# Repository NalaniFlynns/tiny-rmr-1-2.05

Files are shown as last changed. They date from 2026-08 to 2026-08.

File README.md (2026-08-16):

# tiny-rmr-1-2.05 —— RMR 1:2.05 微型反射式红点瞄准镜（固件 + 设计 + 调试器）

> 完整说明书（固件特性/算法/按键操作/NVM 配置/编译烧录/调试）：**[docs/RMR_说明书.md](docs/RMR_说明书.md)**

---

## 更新记录：2026-08-15（晚），固件 V4.3.5：量产版默认禁 SWD/NRST（仅 FLASH_MODE 开放）+ STANDBY1 移除周期轮询唤醒
- **量产版默认禁 SWD + NRST（FEATURE_PROD_SWD_DISABLE，仅 DIRECT/BATT/ECO_D/ECO_B 量产构建生效）**：正常运行时写 SWDCFG/EXRSTPIN 一次性禁用（**仅 POR 可恢复**），SWD/调试口在量产固件中默认关闭；**FLASH_MODE 是唯一调试通道**——每次复位（POR/热复位）后 5 秒 boot 窗口内 BT1 短按 0.8s 进入 FLASH_MODE（任意运行态，含自动开机后的 RUN），窗口内 SWD/NRST 全程开放；窗口结束且不在 FLASH_MODE 即禁用，之后需**重新上电**才能再连。FLASH_MODE 会话内从不禁用，保证烧录通道；退出后由窗口判定补禁。DBG/DBGL 调试版不启用该特性，调试期 SWD 全程可连
- **重新烧录量产固件的操作**：断电 → 重新上电 → **5 秒内短按 BT1（0.8s）** 进 FLASH_MODE（LED 闪两下）→ RMRDebugger 连接烧录；烧录完成复位后如需再次烧录，重复断电上电即可
- **STANDBY1 移除 750ms 周期轮询（省电）**：实测 WUEN/WCOMP + GPIO 边沿唤醒可靠无失败（历史"概率失败"根因是 standby 入口被 WWDT 违规复位/残留标志破坏，V4.3.4 已修复），移除 TIMG14 32k 周期轮询——深睡前停 TIMG14 表，唤醒后重启 1ms tick；消除每 ~750ms 一次的 ~20uA 电流尖峰，standby 电流恒定 <1uA
- **自动关机时长修正**：40min 无操作调暗 + **50min 延迟关机**（TIME_AUTO_SHUTDOWN_S 600→3000，总 90min）
- **省电版（ECO）FLASH_MODE 最小遥测**：POWER_SAVE_BUILD 常态不刷 mailbox 省电，进 FLASH_MODE 后刷最小遥测（VBATT/状态/PWM/standby 计数等）供 RMRDebugger 显示
- **验证**：六变体全部重建（V4.3.5_DBG/DBGL/DIRECT/BATT/ECO_D/ECO_B，0 错误 0 警告）；hex 体检确认 SWDCFG(0x62000001)/EXRSTPIN(0x1E000001) 写序列仅在量产 hex 出现；发布镜像 firmware/RMR.hex = V4.3.5_DIRECT；RMRDebugger 内置 fw/ 同步更新（BATT/DBGL/DIRECT/ECO_D/ECO_B）
- **注意**：量产固件烧录后 SWD 默认关闭属预期；RMRDebugger 在烧录完成复位后若连接在 5s 窗口外断开，属正常行为，重新上电+FLASH_MODE 即可恢复

## 更新记录：2026-08-15（下午），固件 V4.3.4 补丁：修复计时快 6 倍（1.5s 一按就亮/5s 不满）+ 关机不进 STANDBY1
- **修复 1（计时快 ~6 倍，根因）**：MSPM0C110x 的 SYSOSC **实际只能运行在 24MHz**——写 SYSOSCCFG.FREQ=1（4M）寄存器生效但硅片仍以 24MHz 跑，而代码又按 4M 把 TIMG14 LOAD 设成 4000，导致 g_tick_ms 变成 167us/tick。所有基于 tick 的计时（双键 1.5s 开机/关机、5s 模式切换、LVP/ALS 时延）被压缩约 6 倍：表现为"一按就亮、5s 也不满"。修复：`sysclk_set_freq()` 恒定 24MHz、LOAD 恒为 24000-1，g_tick_ms 恒为真 1ms（实测 2036 tick/2s 墙钟）；OFF 态短暂运行不降频（STANDBY1 深睡停机才是 uA 级功耗来源）
- **修复 2（关机后不进 STANDBY1）**：关机路径 `g_off_pending` 在 5s 事件/异常松开后残留为 1，把深睡分支 `!g_off_pending` 卡死 → PMODECFG 恒 0、SWD 不断开。修复：OFF 态深睡前自愈——`g_off_pending && key_is_idle()` 则清零；同时 hal_keys 在干净松开（双键均释放且上一拍非双键）时复位 both_released/both_handled_1_5s/both_handled_5s/both_release_handled/both_down_tick，防止残留导致下一次双按瞬间判定超时长按
- **修复 3（mailbox 时钟上报）**：`sys_clk_khz` 恒报 24000（不再按 SYSOSCCFG.FREQ 报 4000，那只是寄存器假象）
- **修复 4（自动降亮度/关机计时不准，V4.3.4 补丁 2）**：`g_tick_ms % 1000 == 0` 在 delay_cycles 忙等构建（DIRECT/BATT/DBG）主循环 >1ms 时会漏整秒边界（实测计数率仅 0.37/s，40min 会拖到 ~108min）；改为 tick 差值计数（`g_tick_ms - last_sec_tick >= 1000`），实测 1/s 精确，40s 测试参数下 dim 在 ~41s、关机在 ~60s 触发
- **新增 STANDBY 确认计数（mailbox 0xC0）**：`standby_entry_cnt` 每次 OFF 会话第一次真正进入 STANDBY1 前 +1（SRAM 在 STANDBY1 下保留，唤醒后可读）；RMRDebugger 新增 "stby_cnt" 显示 + 修复 sys_clk 显示（新固件报 24000，旧逻辑只认 32000/4000 会显示 "-"）。实测 cmd=7 关机后 stby_cnt 0→1、PMODECFG=1、SWD 断开
- **验证**：六变体全部重建（V4.3.4_DBG/DBGL/DIRECT/BATT/ECO_D/ECO_B，0 错误 0 警告）；RMRDebugger 烧录 RMR_DBGL.hex 后实测：g_tick_ms 真 1ms；mailbox cmd=7 关机后 PMODECFG=1（SYSCTL_PMODECFG_DSLEEP_STANDBY）、内核寄存器不可读、SWD 断开 → **STANDBY1 已真实进入**。实体按键 1.5s 开机/关机、5s 切换待物理验证
## 更新记录：2026-08-15，固件 V4.3.4：修复上电自动开机失效 + STANDBY1 按键无法开机（唤醒加固）
- **修复 1（上电自动开机失效，根因）**：V4.3.3 的 NVM off-intent 哨兵（
eserved[0]=0x5A）用 (cold_boot || !g_off_intent) && !nvm_off_intent_get() 把**冷启动也拦截**——正常断电再上电时 SRAM 丢失但 NVM 哨兵仍在 → 永不自动开机。修复为 cold_boot || (!g_off_intent && !nvm_off_intent_get())：真实上电永远放行 AUTO_POWER_ON（启动成功即清哨兵），仅热复位（WWDT/调试器）带 off-intent 时保持关机
- **修复 2（STANDBY1 按键无法开机，唤醒加固）**：原深睡只依赖 WUEN/WCOMP + GPIO 边沿唤醒，历史概率性失效导致按键无响应。数据手册确认 STANDBY1 下 TIMG14 由 32k LFCLK 驱动且 PD0 中断可唤醒——改为**不停 TIMG14、不屏蔽其中断**，LOAD=24000 → ~750ms 周期中断唤醒轮询按键（STANDBY_TIMG14_LOAD_32K），WUEN 保留即时唤醒；周期唤醒无按键时**跳过 battery_resume 省电**，按键唤醒才重测电压；唤醒后显式 sysclk_set_freq(false) 恢复关机态 4MHz/1ms tick
- **调试信箱尾部扩展（V4.3.4+，0xB8 起）**：追加 sys_clk_khz（SYSOSCCFG.FREQ → 32000/4000）与 oot_refuse_reason（0=OK / 1=测压门拒绝 / 2=off-intent 保持关机 / 3=自动开机未使能）；RMRDebugger 新增 "Sys Clk / Boot Refuse" 遥测显示（旧固件自动显示 "-"）
- **产物**：六变体 hex 全部重建（DIRECT/BATT/ECO_D/ECO_B/DBG/DBGL，V4.3.4），发布镜像 firmware/RMR.hex（V4.3.4_DIRECT）；RMRDebugger 重新编译（rmrdebuger.exe）并更新内置 
w/ 烧录固件
- **掉电保存优化（empty_mspm0c1104.c）**：快速掉电（单次原始电压 < 2000mV 即触发，不再等 3 次采样）→ **瞬间断开 PWM**（直接写 0% 占空比 + 停计数器，LED 停止耗电让电压回升稳定）→ **立即强制保存** NVM → SHUTDOWN（调试版仅保存保 SWD）；缓慢掉电/关机路径（LVP_EXT/LVP_CRIT 连续 5 次采样确认）保持不变——关机才多次采样
- **cfg_params 镜像冻结修复（test_mailbox.c）**：`test_box_sync_cfg()` 同步后未更新 `last_synced_params` 守卫值，导致写配置/模式切换后调试器显示 `cfg_params` 永久冻结为旧值；实机验证（sys_memory.params 0x00020104 vs 镜像 0x00020004）确认并修复
- **说明书重构（docs/RMR_说明书.md）**：前半部分改为**用户手册**——对象用户与阅读指引、快速上手、完整操作手册（开机关机/亮度/模式切换/FLASH）、指示灯速查、机制介绍（低电量/严重低电量/断电保护/测压门控/自动关机/ALS 故障）、12 条常见问题 QA；技术细节（算法/NVM/调试接口/编译烧录）后置
- **产物**：六变体 hex 全部干净重建并逐个体检版本串（DIRECT/BATT/ECO_D/ECO_B/DBG/DBGL），0 错误 0 警告
## 更新记录：2026-08-14，修复“只能切 ALS 无法切回 MAN”
- **根因**：RUN 态双键按住 1.5s 即熄灯进入 OFF，继续按到 5s 时状态已在 OFF，而 OFF 分支的 5s 处理**无条件强制 ALS 开机**——导致从 ALS 永远切不回 MAN（熄灯→5s→又 ALS）
- **修复 1（模式互切）**：`empty_mspm0c1104.c` OFF 态 5s 事件区分来源——来自 RUN 熄灯路径（`g_off_pending`）时**切换 ALS<->MAN 并重新亮灯**；OFF 直接长按/开机失败重试仍为 ALS 快捷开机；NVM 写入改为按位设置支持清零
- **修复 2（ALS 锁定可退出）**：`sys_mode.c` 传感器故障锁定（lockout）后，**ALS 模式仍可切回手动**（原逻辑无条件拒绝所有切换导致卡死）；手动切 ALS 仍被拒以防闪烁循环
- **产物**：六变体 hex 全部重建（DIRECT/BATT/ECO_D/ECO_B/DBG/DBGL）+ 发布镜像 firmware/RMR.hex，0 错误 0 警告

## 更新记录：2026-08-14，无操作超时调整 + 新增完整说明书
- **超时调整**：无操作调暗由 60 分钟改为 **40 分钟**（`TIME_AUTO_DIM_S` 3600→2400），调暗后再 **10 分钟**无操作自动关机（`TIME_AUTO_SHUTDOWN_S=600` 不变）
- **说明书**：新增 [docs/RMR_说明书.md](docs/RMR_说明书.md)（固件特性确认/电压补偿算法/按键操作/状态机/NVM 配置/调试接口/编译烧录）
- **六变体 hex 全部重建**：DIRECT / BATT / ECO_D / ECO_B / DBG / DBGL（含发布镜像 firmware/RMR.hex），源码与 CCS 工作区同步

## 更新记录：2026-08-13，双键关机确认机制（灭灯≠standby）+ RMRDebugger 烧录修复
- **状态**：RUN 态双键满 1.5s 立即熄灯，继续按住到 5s 转 ALS 亮灯
- **机制**：1.5s 熄灯后进入 SYS_OFF，但不再立刻进 STANDBY0（防止 WCOMP/GPIO 唤醒源误触发导致“松开灯又亮”）
- **关机确认**：新增“灭灯≠standby”逻辑，`hal_keys.c` 新增 `EVT_BOTH_RELEASE_1_5S`：1.5s 熄灯后若未满 5s 松开 → 保持关机并进 standby；`empty_mspm0c1104.c` 新增 `g_off_pending` 门控，1.5s 后仅置 pending，确认松开才进 STANDBY0；按住满 5s → 清 pending + 闪烁 + ALS 亮灯
- **RMRDebugger 烧录修复**：`debugworkers.cpp` executeFlash 在 program 前加 `halt` + `flash probe 0`，若 target 无法 halt / FACTORYREGION flash size=0 → 提示 "Target missing or protected"；烧录后清 SRAM 开机门控 `g_off_intent`=0x20000299 / `g_por_magic`=0x2000029C，模拟冷启动自动亮灯（避免“烧录后 OFF 不亮灯”）
- **产物**：DEBUG_LP_BUILD / DEBUG_BUILD / 默认三配置 0 错误 0 警告；`firmware/RMR/hex/RMR_DBGL.hex`（V4.3.3_DBGL）已更新，RMRDebugger 烧录验证：1.5s 熄灯松开后保持 standby，5s 转 ALS + 亮灯
## 更新记录：2026-08-11，深睡后“松开灯又亮”根因修复（双键 1.5s 熄灯 → 松开应保持灭灯）
- 症状：RUN 态双键按住满 1.5s 灯灭后，松开灯又亮（独立供电同样复现）。根因并非按键/邮箱逻辑，而是深睡路径三处硬件级缺陷叠加
- 根因 1（WWDT 拉伸未生效）：进入 STANDBY0 前代码先 `DL_WWDT_restart()` 再写 `WWDTCTL0` 拉伸周期——但 MSPM0 的 WWDT **新周期只在下次计数器重启时装载**，顺序反了导致深睡期间仍是 500ms 周期，约 0.5s 后 WWDT 超时复位设备。修复：**先写 `WWDTCTL0` 拉伸配置，再 `DL_WWDT_restart()`**，深睡时实际生效 ~8192s 周期
- 根因 2（IOMUX 唤醒比较方向错误）：按键为低有效（空闲=1、按下=0），代码却配 `DL_GPIO_WAKEUP_COMPARE_VALUE_1`（匹配高电平）——进 standby 时引脚已为高 → 立即误唤醒/无法保持深睡；按下（1→0）不产生唤醒 → “有概率按键无法开机唤醒”。修复：改为 **`DL_GPIO_WAKEUP_COMPARE_VALUE_0`**（匹配低电平，按下即异步唤醒）
- 根因 3（AUTO_POWER_ON 不区分复位来源）：`FEATURE_AUTO_POWER_ON` 在**任何复位**后都自动开机。WWDT 复位 → 重启 → 看到 NVM 中 auto-power-on 标志 → 直接 RUN → 灯亮。修复：启动时读 `SYSCTL->SOCLOCK.RSTCAUSE`（读后自动清零，仅冷启动 POR/BOR/SHUTDOWN 退出视为 first_boot），**WWDT/SYSRST/调试复位一律保持关机**；`RSTCAUSE` 为 0 时用 `.TI.noinit` SRAM magic 兜底
- 新增观测：`g_test_box.rst_cause`（复用原 `_pad0` 字节，偏移不变，调试器无需改布局）镜像本次复位原因；`g_debug_str` 追加 `Rst:xx` 字段，烧录后可确认复位来源（0x0E=WWDT0 违规）
- 验证：DEBUG_LP_BUILD / DEBUG_BUILD / 默认三配置 0 错误 0 警告；`firmware/RMR/hex/RMR_DBGL.hex`（V4.3.3_DBGL）已更新并已通过 RMRDebugger 烧录（OpenOCD Verify OK）。待独立供电实测：双键 1.5s 熄灯 → 松开保持灭灯；关机态按任意键应立即唤醒（不再等松开）
## 更新记录：2026-08-11，按键交互调整：双键长按 1.5s 立即熄灯 / 5s 转 ALS 亮灯 / 中途松开关机
- **RUN/LVP 态按住双键**：1.5s 到点**立即熄灯**（无需松开），进入 OFF；继续按住到 5s → 闪烁提示（led_blink_twice）并**以 ALS 模式开机**（测压达标才启动，强制写入 ALS 标志并落盘）；1.5s~5s 之间松开 → 保持关机
- **实现**：`hal_keys.c` 1.5s 事件由"仅 OFF 态按住触发"改为全状态按住触发（RUN 态立即响应熄灯）；`empty_mspm0c1104.c` OFF 态新增 `EVT_BOTH_LONG_5S` 分支（闪烁 + ALS 开机）
- **保持原行为**：OFF 态双键 1.5s 开机、RUN 态 5s 模式切换（ALS<->手动，TEST 态同）、FLASH 模式单键 0.8s 进入、调试器恢复出厂指令均不变
- **验证**：DEBUG_LP_BUILD / DEBUG_BUILD / 默认三配置 0 错误 0 警告；`firmware/RMR/hex/RMR_DBGL.hex`（V4.3.3_DBGL）已更新
## 更新记录：2026-08-11，固件深睡唤醒修复（STANDBY0 按键唤醒/进入 standby 概率性问题）
- **根因 1：WWDT 深睡复位**：WWDT 由 LFCLK 驱动，`DL_WWDT_STOP_IN_SLEEP` 只覆盖 SLEEP 模式；进入 STANDBY0 后 LFCLK 继续运行，500ms 看门狗因主循环停摆而超时 → 每 500ms 周期性 SYSRST，导致"有概率无法进入 standby"且按键唤醒被复位窗口吞掉。修复：进入 STANDBY0 前将 WWDT 周期临时拉伸到最大（PER_EN_25 + CLKDIV /8 ≈ 8192s），唤醒后立即恢复 500ms 配置并喂狗
- **根因 2：唤醒源只配了 GPIO 边沿中断**：STANDBY0 深睡下边沿中断依赖 ULPCLK 采样，按下瞬间易被丢失。修复：新增 IOMUX IO 唤醒（`DL_GPIO_setWakeupCompareValue` + `DL_GPIO_enableWakeUp`，WCOMP 匹配高电平、按键按下拉低即异步唤醒），GPIO 边沿中断保留作双保险；唤醒后 `DL_GPIO_disableWakeUp` 清理
- **根因 3：WFI 可被 1ms tick 打断**：进入深睡前清 `GPIOA/TIMG14` pending，并用 `__disable_irq()/__WFI()/__enable_irq()` 受控进入，杜绝"概率性无法进入 standby"的 tick 竞态
- **修复代码位置**：`empty_mspm0c1104.c` OFF 深睡段（STANDBY0 入口/出口），对 `DEBUG_LP_BUILD`、正式版（FLAG_SWD_IN_OFF_STATE 未置位）同样生效
- **验证**：`DEBUG_LP_BUILD=1` / `DEBUG_BUILD=1` / 默认三配置均 0 错误 0 警告；产物 `firmware/RMR/hex/RMR_DBGL.hex`（V4.3.3_DBGL）已更新，建议重新烧录后实测：power off → 深睡（电流应稳定 μA 级无周期性尖峰）→ 双键 1.5s 应 100% 唤醒开机
## 更新记录（2026-08-11，RMRDebugger：Power-Z 平均统计）
- **Power-Z 10s 滑动窗口平均统计**：`PowerZWorker` 新增软件统计——200ms 采样压入窗口、弹出超窗样本，实时计算最近 10s 平均电压/电流/功耗（约 50 样本）
- **GUI**：Power-Z 区域新增一行 `Avg V / Avg I / Avg P / 10s Win(s)` + `Reset Stats` 按钮（清零重填窗口）
- **IPC**：`hello` 与 `powerz` 事件新增 `avg_v / avg_a / avg_w / stat_sec` 字段；新增命令 `{"cmd":"powerz","reset":true}` 清零统计
- **验证**：KM003C 已连接实测——`avg_v` 3.2009V 稳定、窗口满后 `stat_sec` 保持 ~10s、清零后从 0 重新填充；`rmrdebuger.exe` 已更新（firmware/RMRDebugger/ 与 RMR_Factory_Tool_V2.0/）
## 更新记录（2026-08-11，固件 V4.3.3 低功耗调试版 DEBUG_LP_BUILD：OFF 态 WFI/STANDBY0 深睡 + 开机态 SWD，已烧录验证）
- **新增调试编译宏 `DEBUG_LP_BUILD`**（`app_config.h`，默认 0，与 `DEBUG_BUILD`/`POWER_SOURCE_DIRECT`/`POWER_SAVE_BUILD` 正交）：1=低功耗调试专用，版本串 `V4.3.3_DBGL`
- **OFF 态彻底低功耗**：强制进入深睡段（关 ADC/VREF + WFI + STANDBY0，忽略 NVM SWD 位），SWD 自然断开可接受；出厂默认清 `FLAG_SWD_IN_OFF_STATE`
- **开机/运行态 SWD 保持**：RUN 态正常可调试，telemetry 实时；掉电保护不执行 SHUTDOWN（仅存脏配置），主循环 WFI 睡眠等待 1ms tick
- **保留特性**：ECO 动态降频、NVM 校验/重试/多槽位、ALS 故障锁、LVP、FLASH 模式等全部不变
- **产物**：`firmware/RMR/hex/RMR_DBGL.hex`（`V4.3.3_DBGL`）
- **验证**：DEBUG_LP_BUILD=1 与 =0 均 0 错误 0 警告；已烧录测试板：RUN 态 SWD+telemetry 实时；`power off` 后 STANDBY0 深睡（OpenOCD target unknown、数据冻结）；OpenOCD 复位唤醒后自动开机、SWD 自动重连
## 更新记录（2026-08-11，固件 V4.3.3 调试版 DEBUG_BUILD：测试板直供 + 全程 SWD，已烧录验证）
- **新增调试编译宏 `DEBUG_BUILD`**（`app_config.h`，默认 0，与 `POWER_SOURCE_DIRECT`/`POWER_SAVE_BUILD` 正交）：1=测试板直供调试专用，版本串 `V4.3.3_DBG`
- **全程 SWD 保活**（仅调试版生效，其余特性不变）：OFF 态跳过 STANDBY0 深睡段（不关 ADC/VREF、不 WFI 深睡）；掉电保护路径不执行 SHUTDOWN（仅保留脏配置落盘）；出厂默认置位 `FLAG_SWD_IN_OFF_STATE`
- **保留特性**：ECO 动态降频、NVM 校验/重试/多槽位、ALS 故障锁、LVP、FLASH 模式等全部不变
- **产物**：`firmware/RMR/hex/RMR_DBG.hex`（`V4.3.3_DBG`）
- **验证**：DEBUG_BUILD=1 与 =0 两配置均 0 错误 0 警告；已烧录测试板（XDS110 SWD），OFF 态 SWD 连接保持、telemetry 150ms 实时刷新
## 更新记录（2026-08-11，固件 V4.3.3 优化：ECO 动态降频 + NVM 磨损 + ALS 故障锁 + 杂项）
- **ECO 动态降频**：关机/FLASH 态 SYSOSC 切 4MHz 低功耗模式（24MHz→4MHz，睡眠电流大幅下降），开机/运行态自动恢复 24MHz；GPTIMER14 同步重配 LOAD，`g_tick_ms` 恒为真实 1ms（按键 1.5s/5s、FLASH 5min 超时、轮询计时全部不受影响）
- **NVM 磨损优化**：按键调档/模式切换不再立即写 FLASH，只置 dirty 交给 30s 后台自动保存（连按调档只记一次）；关机/LVP/掉电强制保存路径保留
- **ALS 故障锁**：连续 `ALS_ERR_LOCKOUT_COUNT`(3) 次 10s 自恢复后锁定 ALS——拒绝再切回（双键 5s 闪灯提示），防止传感器持续损坏时每 10s 闪一次死循环；重启/恢复出厂解除
- **启动延迟**：ECO 启动后先断 ADC/VREF 寄存器电源域，首次采样/开机测压前再上电；VREF 内部基准采样间隙关闭（`DL_VREF_enable/disableInternalRef` 门控，battery_startup_check/resume 同步）
- **flash 超时差值**：FLASH 模式 5min 超时改 `g_tick_ms` 差值比较（原累加计数，防 49.7 天回绕）
- **验证**：DIRECT / BATT / ECO_D / ECO_B 四变体 0 错误 0 警告；未烧录

## 更新记录（2026-08-11，固件 V4.3.3 省电版 ECO：关闭一切非必要开销，未烧录仅编译验证）
- **新增省电编译宏 `POWER_SAVE_BUILD`**（`app_config.h`，默认 0，与 `POWER_SOURCE_DIRECT` 正交）：1=省电版，版本串 `V4.3.3_ECO_D`（直连）/ `V4.3.3_ECO_B`（电池）
- **省电措施**：主循环 24MHz 忙等改 `__WFI()` 睡眠等待 1ms tick 中断（GPTIMER14 唤醒）；调试箱 `test_mailbox_task` 每 tick 实时刷新整体关闭（GPIO 读/64 位乘除/镜像同步/诊断计算）；ADC/VREF 采样间隙断电、采样间隔 500ms（原 100ms，LVP 去抖 5 次约 2.5s 响应）；OPT3001 手动模式与 OFF 态发 shutdown 配置（0.4µA 级，原连续转换约 1.8µA）；ALS 轮询 1s（原 120ms，转换占空比约 10%）；LED 亮度/状态未变化时不重算 PWM（原每 tick 64 位乘除+写寄存器）；出厂默认清 SWD 保活位 -> OFF 态进 STANDBY0 深睡（µA 级）
- **注意**：烧录省电版后若 NVM 已有旧配置（features=0xFF），OFF 态仍不会进 STANDBY0；需"恢复出厂"或经调试器清 bit6 才生效；省电版 OFF 态 SWD 不可访问（深睡保电），日常调试请用普通版
- **产物**：`firmware/RMR/hex/RMR_DIRECT_ECO.hex`（`V4.3.3_ECO_D`）、`RMR_BATT_ECO.hex`（`V4.3.3_ECO_B`）；普通版 DIRECT/BATT hex 同步刷新
- **验证**：DIRECT / BATT / ECO_D / ECO_B 四变体全部 0 错误 0 警告；未烧录（设备仍运行 V4.3.3_DIRECT）

## 更新记录（2026-08-11，固件 V4.3.3：FLASH 模式长按 1.5s 开机 + 调试器 cfg_features 实时显示）
- **固件 V4.3.3**：进入 FLASH 模式后双键长按 1.5s 也可正常开机——与 OFF 态一致先 `battery_startup_check()` 测压达标才启动（达标→SYS_RUN+mode_init，不达标→LED 闪 100ms 提示）；FLASH 模式 5 分钟超时自动复位逻辑保留
- **调试器修复**：telemetry 新增 `cfg_features`（mailbox 偏移 0x78，授权后实时显示 0xFF），修复此前该字段恒为 0 被误判为 features 被清零的问题；实际设备 features 一直是 0xFF（自动开机/无操作调暗/LVP/standby 位全开），OFF 态不进 STANDBY0 保持 SWD 可访问属设计行为（bit6 置位）
- **产物**：`firmware/RMR/hex/RMR_DIRECT.hex`（`V4.3.3_DIRECT`）、`RMR_BATT.hex`（`V4.3.3_BATT`）；`RMR_Factory_Tool_V2.0/rmrdebuger.exe` 已更新
- **实测**：unlock 后 cfg_features=0xFF、feat=255、magic=0x54455354；FLASH 开机链路 state 0→3→1 全程 SWD 真机验证（GPIOA 模拟 BT1 短按进 FLASH，双键 1.6s 松开正常开机）

## 更新记录（2026-08-10 深夜，固件 V4.3.2 + 调试器：虚拟按键真实语义 + 连接自动清理）
- **固件 V4.3.2**：虚拟按键注入条件由「TEST 态 + magic」放宽为「授权(magic+host_version)后任意状态生效」，与真实按键走同一套去抖/事件状态机；TEST 态保持当前模式——ALS 就是 ALS（走真实 OPT3001 传感器曲线）、MAN 就是 MAN（走档位亮度），不再被测试态强制切模式；`+` 键 MAN 加档 / ALS 偏移+，`-` 键 MAN 减档 / ALS 偏移-，双键 5s 切换 ALS<->手动，均与真实按键一致
- **调试器自动清理**：OpenOCD 连接失败/初始化失败时自动 `taskkill` 残留 openocd.exe 进程（上次崩溃/异常遗留、占用 XDS110 或 3334 端口导致连不上），限频 5s 防抖，清理后自动重启 openocd 重连；IPC `key` 命令与 UI 虚拟按键一致，非 TEST 态先自动解锁
- **产物**：`firmware/RMR/hex/RMR_DIRECT.hex`（`V4.3.2_DIRECT`）、`RMR_BATT.hex`（`V4.3.2_BATT`）；`RMR_Factory_Tool_V2.0/rmrdebuger.exe` 已更新
- **实测**：XDS110 + MSPM0C1104 上验证 MAN 加减档、ALS 偏移加减、双键 5s 模式切换、模式保持；模拟残留 openocd 占用探针后重启调试器，自动清理并重连成功

## 更新记录（2026-08-10，固件 V4.3.1 双版本：直连 / 2xSR516SW 电池）
- **双版本编译**：`app_config.h` 新增编译期电源模式宏 `POWER_SOURCE_DIRECT`——`1`=稳压电源直连版（1.6-3.6V 可调电源 + 120-635Ω 可调限流电阻，不算电池内阻），`0`=电池版（2x SR516SW 串联 3.1V 标称，计入电池内阻）
- **产物**：`firmware/RMR/hex/RMR_DIRECT.hex`（版本串 `V4.3.1_DIRECT`）、`firmware/RMR/hex/RMR_BATT.hex`（版本串 `V4.3.1_BATT`）；出厂默认 `r_series`：直连=360000mΩ（限流电阻），电池=410000mΩ（360Ω 限流 + 2×25Ω 电池内阻，SR516SW 规格书未标注内阻，取氧化银纽扣电池典型值，可经调试器写 NVM `r_series` 校准）
- **器件规格核对**：LED=APTD1608SECK/J4-PF（超亮橙 AlGaInP，VF 2.2V 典型/2.8V max @20mA，IF DC 30mA max）——固件 `HW_LED_FORWARD_V_MV=2200`、`HW_LED_MAX_CURRENT_UA=2800` 与规格书一致；电池=SR516SW（1.55V、12.5mAh、标准放电 20µA）；MCU=MSPM0C1104（Cortex-M0+，10-bit ADC，1.4V 内部 VREF，无 SysTick 用 GPTIMER14）
- **注意**：升级烧录后若 NVM 已有旧配置，`r_series` 等参数保留旧值；需"恢复出厂"或调试器写入以应用新默认参数
## 更新记录（2026-08-10，调试器：接入 Power-Z KM003C 真实电压电流计）
- **硬件接入**：RMRDebugger 新增 Power-Z KM003C（VID 0x5FC9 / PID 0x0063）真实电压电流计支持，通过 Windows HID 接口（Basic Mode，免驱动）以 200ms 间隔轮询 ADC（GetData 0x0C → PutData 0x41，44 字节 AdcDataRaw）
- **遥测显示**：监视器固定长条新增一行 6 位小数实时数据：真实电压 V / 真实电流 A / 实时功耗 W（=V×I）/ 平均电压 V / 平均电流 A / 温度 °C；连接状态实时指示（绿=已连接，红=断开，拔插自动重连）
- **IPC 扩展**：新增 `{"type":"powerz", ...}` 广播帧（`vbus_v` / `ibus_a` / `vbus_avg_v` / `ibus_avg_a` / `power_w` / `temp_c`），`hello` 响应新增 `powerz` 字段（含 connected 与最新值），供外部工具与自动化直接读取
- **新增源码**：`firmware/RMRDebugger/PowerZWorker.{h,cpp}`（HID 枚举/读写/解析/重连），CMake 链接 `hid`/`setupapi`
# tiny-rmr-1-2.05 — RMR 智能照明控制项目

基于 **TI MSPM0C1104**（Cortex-M0+）的低功耗智能照明/测试设备完整项目，包含：

- `firmware/RMR` — 设备固件（CCS 21 工程，tiarmclang，当前版本 **V4.3.4_DIRECT / V4.3.4_BATT**）
- `firmware/RMRDebugger` — 上位机调试器（Qt 6.11 + MinGW，支持 XDS110 SWD）
- `RMR_Factory_Tool_V2.0` — 已打包的出厂调试工具（含 Qt 运行库 / OpenOCD / USB 驱动）
- `PCB` / `model` / `image` — 硬件、结构与渲染资料

---

## 更新记录（2026-08-10，V4.3.1 增量 7：1ms 硬件时基 GPTIMER14）
- **根因**：MSPM0C1103/1104 硬件上没有 SysTick（TI E2E 确认，寄存器写入无效、读取恒为 0）——此前用 SysTick_Config 做 1ms 时基实际永不触发，所有毫秒计时（按键 5s 模式切换 / 1.5s 关机 / LVP / ALS 10s 自恢复等）全部卡死或异常
- **修复**：改用空闲的 **GPTIMER14** 周期中断做 1ms 硬件时基（24MHz BUSCLK，period=23999），g_tick_ms 由 TIMG14_IRQHandler 驱动；接口不变，所有基于 g_tick_ms 的计时恢复正常
- **实测**：设备复位后 g_tick_ms 每秒稳定递增，调试信箱实时刷新正常

## 更新记录（2026-08-11 凌晨，V4.3.1 增量 6）

- **虚拟按键与真实按键语义完全一致**：`[+]`/`[-]`/`[+&-]` 改为真实 `pressed`/`released` 路径——按住=注入按下（同时拦截物理键），松开=真正松开（解除拦截）；按下时长=实际按住时长（按钮实时显示 `PRESSED x.x s`）；快速点击 <120ms 补足到最短有效时长（等效真实按键去抖，防止 SWD 写队列延迟吞掉短按）
- **状态与操作合并显示**：监视器条原 `Btn[-]`/`Btn[+]` 两个状态格移除，按键状态直接显示在操作按钮上——注入按住=红底 `PRESSED+秒数`、注入未按住=`OVR`、物理键按下=琥珀底 `PHY`、均无=默认；修复 PHY 状态极性判断（固件 raw_key=1 表示按下，此前 `!raw` 判定正好相反）
- **State 格显示 ALS/手动**：`RUN`/`TEST` 状态后追加 ` ALS`/` MAN`（如 `RUN MAN`、`TEST ALS`），由固件每 tick 同步的 params 位 8 驱动
- **未解锁自动进入测试态**：虚拟按键按下时若设备不在 TEST 态自动执行解锁（ENTER_TEST），保证按下即有响应，与真实按键行为一致
- **松开丢失看门狗**：按键按住期间每 100ms 用系统物理鼠标状态（`GetAsyncKeyState`，而非 Qt 内部可能卡住的状态）检测——若左键已松开但按钮仍标记按住（松开事件丢失/窗口失焦/外部注入），自动强制真正松开，避免虚拟键在固件侧被持续注入、误触发 5s 双键模式切换
- **连接时清空残留覆盖**：切换/激活探针时自动写 0 清空 `ovr_key_minus/plus/block/als_en/led_mode`，防止上次会话残留的覆盖位继续作用于固件
- **固件**：TEST 态 LED 按键输出与真实模式一致（ALS 走 `mode_task()`、手动走 `CFG_BRT_MAP`），TEST 态按键分发补齐 `EVT_BOTH_LONG_5S`

## 更新记录（2026-08-10 深夜，V4.3.1 增量 6：电压降额 + PWM 补偿）
- **根因修复**：`battery_brt_to_pwm` 原来用 `min(i_peak, i_max)` 计算满亮度电流，3.0V 时峰值电流约 2.1mA 恒低于 2.8mA 上限，导致 PWM 占空比恒等于 brt、与电压无关；已改为恒流模型 `i_req = brt*i_max/1000`，`duty = i_req/i_peak`，电压下降时占空比自动升高维持亮度
- **电压线性降额**：新增 `V_DERATE_FULL_MV 3300`；`battery_get_safe_brt` 在 2400mV→30、3300mV→1000 之间按电压线性缩放安全亮度上限，低电压下自动限制档位与亮度（实测 @2.88V safe≈547）
- **刷新修复**：删除 BRT 缓存，电压变化（30mV 以上）不再冻结显示；LVP 分支同样刷新 `g_safe_brt_out`
- **构建根治**：CCS21 工程改用 post-build `tiarmobjcopy -O ihex` 生成 HEX（停用 tiarmhex），根治版本段错误；`.cproject` 已更新
## 更新记录（2026-08-10 晚，V4.3.1 增量 5）
- **固件 brt→PWM 全量程线性修复**：`battery_brt_to_pwm` 新增 `min(i_peak, i_max)` 钳位，`brt 0-1000` 从头到尾线性映射到 0-100%（此前烧录版本在 brt≈980 就提前饱和 100%）；同时修复 WALL 电压下限计算的 uint32 下溢（低电压时功率墙失效问题）
- **LVP_CRIT 迟滞自恢复**：进入 `SYS_LVP_CRIT` 后当电压回升 +100mV（`BATT_STARTUP_HYSTERESIS_MV`）自动恢复 `SYS_RUN`，根治低电压时的 2s 周期債动闪烁（明亮每 2s 瞬间暗一下）和长期卡在 LVP 状态问题
- **调试器 PWM 显示**：监视栏 PWM 改为“当前值 / 2399”，与寄存器原始值对应
- **图表实时刷新修复**：图表数据改用批量 `replace()` 裁剪窗口外点（避免逐个 `remove(0)` 触发 QtCharts 重排异常），并新增 200ms 定时强制重绘；Y 轴自适应新增最小跨度（电压 250mV / 光照 2000 / PWM·BRT 200），避免 raw ADC 噪声被放大成尖峰
- **进入测试态不再闪灭**：调试授权（unlock）进入 TEST 时保持当前亮度（ovr_brt_val 默认取 g_current_brt），修复此前 ovr_brt_val=0 导致进入测试模式瞬间 LED 熄灭闪烁的问题
- **调试邮箱 cfg_params 每 tick 同步**：固件每次主循环刷新邮箱镜像，调试器监视器新增 “Params” 格实时显示 params hex，点虚拟按键 +/- 立即可见挡位/ALS偏移变化（此前只是进入测试态时的快照）
- **虚拟按键功能修复（图形界面）**：修复布局重构时丢失的 `vOvr->addLayout(lKey)`，软件按键 [+]/[-]/[+&-] 与 Tap 版本恢复可见；拆分为两行（按键行 + Hold/Tap 行）避免宽度溢出；修复 `&` 被 Qt 当作快捷键前缀导致按钮显示 [+-] 的问题（改为 [+&&-] 显示 [+&-] ）
- **OpenOCD 端口修复**：Tcl 端口改用 `3334 + 探针序号`，避开 Windows Hyper-V/WinNAT 动态排除端口段（6515-6714 ，含 6666），修复 XDS110 无法绑定 Tcl 端口导致连接失败的问题

## 更新记录（2026-08-10 晚，V4.3.1 增量 4）
- **固件硬件功率估算**：调试邮箱新增 `est_hw_power_uw`（0xB4）= 原始电池电压 x 当前 PWM 反推平均电流，GUI 显示 mW 小数点后三位
- **ALS 最低亮度**：`ALS_MIN_BRT` 50 → 30，无论安装环境多暗亮度不低于 brt=30
- **调试器图表重构**：拆分为三张图一行（电压 / 环境亮度 / PWM+BRT），X 轴自动滚动显示最近400点窗口，Y 轴比例尺自适应（按窗口数据 min/max + 8% 边距）
- **软件按键触发**：GUI 新增 [+&-] 同时按键（长按 1.5s = OFF 开机 / RUN 关机，5s = ALS ↔ 手动切换）；所有软件按键按下时自动拦截物理按键，松开后解除；IPC `key` 支持 plus/minus/both + block 参数

更新记录（2026-08-10 晚，V4.3.1 增量 3）
- **固件 LED 亮度映射修复**：`HW_LED_MAX_CURRENT_UA` 出厂默认由 30000 修正为 **2800 uA**（贴实测峰值电流 ~2744 uA），根治 `brt>=91` 后 PWM 占空比即饱和 100%、ALS 亮度变化不可见的问题；`brt 0-1000` 现在全程线性映射（brt=50→5%、100→10%、300→30%、1000→100%）

更新记录（2026-08-10 下午，V4.3.1 增量 2）
- **调试器布局**：左右两列改为可拖动 QSplitter；所有分栏（全局/右侧日志列/图表与列/双列）支持鼠标拖动调整比例并记忆（归一化比例存储 + 页签切换/窗口缩放时延迟应用，不依赖页签可见性）
- **ALS 亮度映射预览**：“Fake Lux”注入时实时显示预期 Brt%/PWM，参考固件 `als_lux_to_brt` 公式（7*sqrt 曲线 + 5 档偏移 + 低/高量程钳位），依据当前配置计算
- **IPC 调试接口增强**：新增 `tab`（切换页签）、`autotest`、`calib` 命令；`led` 兼容 `value/pwm/brt` 字段；`layout` 支持比例设置/读取
- **AUTO-TEST 修复**：亮环境注入改为 50000 lux（原 5000 在最低亮度 50 时无法区分 dark/bright）；PWM 判定条件反转（寄存器值越小越亮）
- **固件修复**：cmd6 从 TEST→RUN 时补调 `mode_init()`，避免退出测试模式后 ALS 标志未初始化导致无法自动感光

## 更新记录（2026-08-10，V4.3.1 增量）
- **固件**：调试信箱新增 
batt_raw_mv（偏移 0xB0，每 tick 镜像原始 ADC 电压，未滤波）
- **调试器**：SEND_SYS_CMD(3) 写配置改为“仅写 map 提供的字段”，空 map 不再清 NVM；cfg_params 只改低 8 位默认档位，保留 ALS(bit8)/offset(bit16-23) 高位
- **调试器 UI**：实时遥测改为固定高度长条（不随窗口缩放）；图表缩小为固定高度并限制 400 点数（防长期运行卡死）；电压显示原始 ADC 值（不平滑）

## 固件 V4.3.1_PROD

### 核心功能
- **亮度控制**：9 档亮度（`CFG_BRT_MAP`），按键短按调档；无限制亮度/PWM 注入（测试模式）
- **ALS 环境光自适应**：OPT3001 光照传感器，滤波 + 高低阈值钳位，亮度下限 `als_min_brt`（默认 30）
- **电池管理**：峰值/平均电流估算（峰值 × 实际 PWM 占空比）、动态内阻、LED 电压/功率估算、安全亮度上限
- **LVP 低电压保护**：临界/扩展两级保护，**5 次计数去抖**，临界进入 `SYS_LVP_CRIT`，扩展触发闪烁提示
- **ALS 故障保护**：连续 **3 次** 读取失败进入 `SYS_ALS_ERR`（LED 闪烁提示），**10 秒后自动恢复**
- **NVM 掉电保存**：配置掉电保存（`nvm_mark_dirty` + 后台写 Flash）
  - FNV-1a CRC32 写入后校验，失败 **3 次重试**
  - **多槽位**（`NVM_MAX_SLOTS`）轮换写入 + 坏块标记 + 磨损均衡
  - 擦写耗时补偿，保存计数 `seq_id`、槽位/扇区地址上报调试信箱
- **状态机**：`SYS_OFF → SYS_RUN → SYS_LVP_CRIT / SYS_FLASH_MODE / SYS_TEST_MODE / SYS_ALS_ERR`，按键长按组合支持 ALS 模式切换、恢复出厂
- **测试模式（Mailbox）**：SWD 写 `0x54455354` 授权进入，支持：
  - `cmd 2` 复位 / `cmd 3` 写配置（mask 过滤）/ `cmd 4` 保存 / `cmd 5` 恢复出厂+保存 / `cmd 6` 开机退出 / `cmd 7` 关机退出
  - 授权丢失 → 立即复位；正常退出 → `SYS_FLASH_MODE`
  - 按键/ALS/亮度/PWM 注入，物理按键屏蔽
- **烧录后清存储区**：配置项 `DEV_CLEAR_NVM_ON_POR`（1 = 烧录后首次上电清空存储区恢复出厂，默认 0）

### 调试信箱（Test Mailbox，SRAM 0x20000000）
每 tick 刷新实时数据供调试器读取：magic/版本、命令与应答、电压电流估算、档位/亮度/PWM、安全亮度、ALS 原始/滤波值、传感器状态与错误计数、按键状态、状态机镜像、NVM 状态（dirty/失败计数/序列/槽位）、全部配置镜像（`cfg_*`）、固件版本串。

### 构建
1. 用 CCS 21 导入 `firmware/RMR`（需 MSPM0 SDK，`ti_msp_dl_config` 由 syscfg 生成）
2. 根目录 `makefile.init` 已加入 post-build 钩子：链接后用 **tiarmobjcopy** 重新生成 Intel HEX，根治 `tiarmhex` 的 `.fw_version` 段内容错误
3. 命令行构建（Debug 目录）：

```bat
set PATH=C:\ti\ccs2100\ccs\utils\bin;C:\ti\ti_cgt_arm_llvm_4.0.2.LTS\bin;%PATH%
cd Debug
gmake -f makefile all
```

产物：`Debug/RMR.hex`（亦同步为仓库根 `firmware/RMR.hex`）。

---

## 调试器 RMRDebugger（Qt 6.11）

### 功能
- **XDS110 / DAPLink 自动扫描**（OpenOCD SWD，默认 100 kHz，可 5 kHz–4 MHz 切换）
- **实时遥测**：150 ms 轮询（可调），显示电压/电流/功率/内阻/档位/亮度/PWM/ALS/NVM 等全部信箱字段，图表实时刷新
- **烧录**：一键擦除+编程+校验+复位（`program verify reset`），进度/日志全显示
- **测试模式**：解锁（授权进入）、读配置、写配置（mask 过滤）、保存、恢复出厂+保存、开机/关机退出、软复位
- **注入调试**：模拟按键（+/- 短按）、ALS 注入（开/关 + lux）、LED 注入（PWM 直驱 / 无限制亮度 / 受限亮度）
- **隐藏 IPC 接口**：`127.0.0.1:7345`，JSON 行协议，供外部脚本/自动化实时读写（见下）

### 构建
```bat
set PATH=C:\Qt\6.11.1\mingw_64\bin;C:\Qt\Tools\mingw1310_64\bin;C:\Qt\Tools\CMake_64\bin;C:\Qt\Tools\Ninja;%PATH%
cmake -S firmware\RMRDebugger -B build -G Ninja -DCMAKE_BUILD_TYPE=Release
cmake --build build
```
运行前确保 `openocd.exe` 与 XDS110 驱动可用；程序内可配置 OpenOCD 路径与脚本目录。

### IPC 接口（127.0.0.1:17345）
连接后立即收到 `hello`（含探针列表/当前状态/最近遥测）。请求/响应均为单行 JSON，换行分隔。

命令（`{"cmd": ...}`）：

| cmd | 参数 | 说明 |
|---|---|---|
| `ping` | — | 健康检查，返回 `pong` |
| `state` | — | 重新发送 `hello` |
| `scan` | — | 重新扫描探针 |
| `setfw` | `path` | 设置固件路径 |
| `flash` | `path?` | 烧录（含校验） |
| `unlock` | — | 进入测试模式 + 读配置 |
| `syscmd` | `n` | 系统命令 2/3/4/5/6/7 |
| `cmd` | `type,arg1,arg2,map` | 通用命令（WRITE_8/16/32、READ_CFG、SEND_SYS_CMD…） |
| `write` | `ofs,val,size` | 写信箱偏移 |
| `read` | `ofs,size` | 读信箱偏移，回 `memread` 事件 |
| `poll` | `enabled,intervalMs` | 启停轮询 |
| `speed` | `khz` | 切换 SWD 速度 |
| `key` | `tap(1=+),holdMs` | 模拟按键 |
| `power` | `state(on/off)` | 开机/关机并退出测试模式 |
| `led` | `mode,value` | LED 注入（1=PWM、2=无限制亮度、3=受限亮度） |
| `als` | `enabled,lux` | ALS 注入 |

事件（`{"type": ...}`）：`hello`、`reply`、`status`、`uuid`、`fwver`、`progress`、`log`、`msg`、`config`、`telemetry`、`memread`、`probe_added`、`probe_removed`、`active`。

示例：

```json
{"cmd":"unlock"}
{"cmd":"flash"}
{"cmd":"poll","enabled":true,"intervalMs":150}
```

### RMRBuildTool IPC 接口（127.0.0.1:17346）
启动时可用命令行第一个参数预选工程目录: 
mrbuildtool.exe <工程目录>。
连接后立即收到 hello。请求/响应均为单行 JSON，换行分隔。

命令（{"cmd": ...}）：

| cmd | 参数 | 说明 |
|---|---|---|
| ping | — | 健康检查，返回 pong |
| state | — | 重新发送 hello |
| setdir | path | 设置工程目录（需包含 app_config.h） |
| setgmake | path | 设置 gmake.exe 路径 |
| setversion | 
er | 设置版本号 |
| setnote | 
ote | 设置更新说明（仅随加密容器嵌入） |
| 
ariant | ll | 构建范围: false=默认 DBGL, true=全部 6 变体 |
| uild | ll,version,note | 开始构建（clean+all，完成后还原默认配置并重建） |
| stop | — | 停止构建 |
| genpwd | — | 重新生成强密码（reply 与 password 事件携带） |
| getpwd | — | 读取当前密码 |
| setpwd | password | 设置密码 |
| setauth | uth | 解锁方式 1=密码 2=FIDO2 3=通行证 |
| ncrypt | in,out,auth,password,version,note,blockSize,credId | 生成 FWSEC1 加密固件 |
| creds | — | 列出 FIDO2/通行证凭据 |
| quit | — | 退出程序 |

事件（{"type": ...}）：hello、
eply、state、log、progress、uild_finished、password、ncrypt_progress、ncrypt_finished。

示例：

`json
{"cmd":"setdir","path":"C:/repo/firmware/RMR"}
{"cmd":"build","all":true}
{"cmd":"genpwd"}
`

---
## 烧录方法（XDS110）

```bat
openocd -s <openocd>\scripts -f interface/xds110.cfg -f target/ti_mspm0.cfg ^
  -c "transport select swd" -c "adapter speed 1000" ^
  -c "tcl_port 3334" -c "gdb_port disabled" -c "telnet_port disabled"
```
TCL 端口使用 **3334**（避开 Windows Hyper-V 保留段 6515–6714）。也可直接在调试器 GUI 中一键烧录。

---

## 目录结构
```
tiny-rmr-1-2.05/
├── firmware/
│   ├── RMR/            # MSPM0C1104 固件工程（CCS 21）
│   ├── RMRDebugger/    # Qt 调试器源码
│   └── RMR.hex         # 当前发布固件镜像（V4.3.1）
├── RMR_Factory_Tool_V2.0/  # 打包版调试工具（免编译）
├── PCB/                # 原理图/PCB/打样文件
├── model/  image/      # 结构与渲染资料
└── README.md
```

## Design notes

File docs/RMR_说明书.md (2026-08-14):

# RMR 1:2.05 微型反射式红点瞄准镜 —— 说明书

> 适用固件：V4.3.3（2026-08）｜主控：TI MSPM0C1104（Cortex-M0+ 24MHz）｜调试/烧录接口：SWD（无 UART）
>
> 本文档前半部分为**用户手册**（操作、指示灯、机制介绍、常见问题），后半部分为**技术说明书**（算法、NVM、调试接口、编译烧录）。不同读者可按下方指引直接跳转。

---

# 第一部分 用户手册

## 1. 对象用户与阅读指引

| 读者 | 关心内容 | 建议章节 |
|---|---|---|
| **最终使用者 / 射手** | 怎么开机、调亮度、切换模式、电池能用多久、灯闪是什么意思 | 第 2 章 快速上手、第 3 章 完整操作手册、第 4 章 指示灯、第 5 章 机制介绍、第 6 章 常见问题 |
| **装配 / 产线测试人员** | 出厂状态检查、烧录、恢复出厂、开关机时序、低电压验证 | 第 3 章 完整操作手册、第 5 章 机制介绍、第 15 章 调试接口、第 16 章 编译与烧录 |
| **维修 / 售后人员** | 故障现象判断、ALS 故障、低电量保护、掉电保存、恢复出厂 | 第 4 章 指示灯、第 5 章 机制介绍、第 6 章 常见问题 |
| **固件 / 硬件开发人员** | 状态机、亮度算法、电压补偿、NVM 布局、调试信箱协议 | 第 7 章起全部技术章节 |

产品定位：RMR 1:2.05 是一款**微型反射式红点瞄准镜**（红色反射式红点），LED 红点亮度可调，支持手动 9 档亮度与自动感光（ALS）两种模式，采用 2×SR516SW 氧化银纽扣电池供电，针对**长时间待机、低功耗、掉电不丢配置**做了专门设计。

## 2. 快速上手

1. **安装电池**：装入 2×SR516SW 纽扣电池（标称 3.1V，注意极性）。
2. **开机**：同时按住 **BT1 + BT2 两颗键 1.5 秒**。电压达标（> 约 2.2V）即亮灯，进入上次保存的模式（出厂为手动模式默认第 4 档亮度）。
   - 若在关机状态下**直接长按双键满 5 秒**：双闪提示后以**自动感光（ALS）模式**开机。
3. **调节亮度**：开机状态下——
   - **BT2（+）短按**：手动模式升一档；ALS 模式偏移 +30%（最高 +50%）。
   - **BT1（-）短按**：手动模式降一档；ALS 模式偏移 -30%（最低 -50%）。
4. **关机**：同时按住双键 **1.5 秒熄灯后松开**（未按满 5 秒）即确认关机，进入深睡省电。
5. **使用提示**：红点亮度在 ALS 模式下自动跟随环境光；长期无操作会自动调暗、关机以省电；低电量时 LED 会每 2 秒闪一下提示（见第 4、5 章）。

> 若开机无反应（灯不亮），请检查电池电压：电压低于约 2.2V 时保护机制会拒绝开机，属于正常保护行为（见 5.4 节）。

## 3. 完整操作手册

### 3.1 按键说明

两颗物理按键（低有效，硬件去抖）：

- **BT1（-）**：短按降亮度 / 偏移减
- **BT2（+）**：短按升亮度 / 偏移加
- **双键（BT1+BT2 同时）**：开关机、模式切换、进入 FLASH 模式

### 3.2 开机

| 操作 | 触发条件 | 结果 |
|---|---|---|
| 双键按住 1.5s | 关机态，电压达标（> lvp_ext+100mV ≈ 2.2V） | 开机，进入上次保存的模式（手动/ALS）与档位 |
| 双键按住 1.5s | FLASH 模式 | 测压开机（与关机态一致） |
| 双键直接按住满 5s | 关机态 | 双闪提示 + **以 ALS 模式开机**（电压达标；失败会再试一次） |
| 上电（冷启动） | 仅 POR/BOR/SHUTDOWN 退出等冷启动原因 | 自动开机（FEATURE_AUTO_POWER_ON）；调试复位/看门狗复位不自动开机 |

电压不达标时：LED 闪 100ms 提示，保持关机。

### 3.3 关机与深睡

| 操作 | 结果 |
|---|---|
| 运行中双键按住 1.5s | 立即熄灯进入“待关机”状态 |
| 熄灯后松开（未满 5s） | 确认关机 → 进入 STANDBY0 深睡（µA 级） |
| 熄灯后继续按住满 5s | 双闪提示 + **切换 ALS⇄手动并重新亮灯**（电压达标） |

> 关键点：**灭灯 ≠ 立即深睡**。必须“松开且未满 5s”才会真正进入深睡；一直按到 5s 则变成模式切换。这是刻意设计，防止误触关机后又唤醒。

### 3.4 亮度调节（运行中）

手动模式（MAN）：9 档亮度，映射 brt = {5, 20, 50, 150, 300, 450, 600, 800, 1000}，出厂默认第 4 档（300）。

| 操作 | 手动模式 | ALS 模式 |
|---|---|---|
| BT2 短按 | 亮度升一档（受电压安全上限约束，越限档仍可升但会标记 overshot） | 亮度偏移 +30%（+50% 封顶） |
| BT1 短按 | 亮度降一档（已越限时先回落到安全亮度） | 亮度偏移 -30%（-50% 封底） |

### 3.5 模式切换（ALS ⇄ 手动）

- 运行中：**双键按住 1.5s 熄灯 → 继续按满 5s** → 双闪提示，自动在 **ALS ⇄ 手动**之间切换并亮灯（电压达标）。
- 关机态：直接**双键长按满 5s** → 以 ALS 模式开机。
- ALS 传感器连续 3 次故障自恢复后锁定 ALS 时：当前在 ALS 仍可切回手动；手动试图切 ALS 会被拒绝（双闪提示），避免传感器永久损坏时反复闪烁。

### 3.6 FLASH 模式（烧录/调试模式）

| 操作 | 结果 |
|---|---|
| 关机态按住 BT1 0.8s（电压达标，冷启动后仅一次） | 进入 FLASH 模式：VCC_EN 拉高、NRST 恢复、SWD 可连接 |
| FLASH 模式中双键 1.5s | 测压开机，退出 FLASH 模式 |
| FLASH 模式 5 分钟无操作 | 自动复位 |

### 3.7 无操作自动调暗 / 关机

- **40 分钟**无任何按键操作 → 自动调暗到最低亮度（brt=5）。
- 调暗后再过 **10 分钟**仍无操作 → 自动关机。
- 任意按键事件立即恢复亮度并重新计时。

## 4. 指示灯（LED）状态速查

| 现象 | 含义 |
|---|---|
| 常亮（亮度按档位/ALS 曲线） | 正常运行 |
| 双键 1.5s 后熄灭 | 进入待关机，松开确认关机 |
| 熄灯后按住至 5s 时**双闪** | 模式切换提示（ALS⇄手动） |
| 开机失败时闪 100ms | 电压不达标，拒绝开机 |
| **每 2s 闪 50ms** + 亮度降到 1/4 | **低电量警示**（电压 < 2.3V，见 5.1） |
| **每 1.5s 周期闪（亮 600ms）** | **ALS 传感器故障**（连续 3 次读取失败，见 5.6） |

## 5. 机制介绍（用户视角）

### 5.1 低电量模式（LVP_CRIT）

- 触发：电池电压**连续 5 次采样 < 2300mV**。
- 表现：LED **每 2 秒闪 50ms** 提示低电量，同时亮度自动降为 1/4，优先保证还能继续使用一段时间。
- 恢复：电压回升到 2400mV 以上自动恢复正常模式。
- 作用：避免电压过低时 LED 突然熄灭或电流异常，让用户有足够时间更换电池。

### 5.2 严重低电量保护（LVP_EXT 关机）

- 触发：电压**连续 5 次采样 < 2100mV**。
- 动作：**立即关机**，并在关机前自动保存当前配置（档位/模式/偏移）。
- 目的：防止电池过放损坏电池寿命；配置不会丢，换电池后开机自动恢复。

### 5.3 断电保护（掉电保存）

- 触发：检测到**快速掉电**（单次原始电压 < 2000mV 即触发，不等待多次采样）。
- 动作：**瞬间断开 PWM**（LED 立即停止耗电，让电压回升稳定）→ **立即强制保存**配置到 Flash（NVM）→ 进入 SHUTDOWN（断电保护态）。DBG/DBGL 调试版不 SHUTDOWN，只保存配置以保持 SWD 可连。
- 时序保证：先断 PWM 再擦写 Flash，避免掉电瞬间 LED 继续拉电流导致电压塌陷、NVM 擦写中断丢配置。
- 关机才多次采样：缓慢掉电（< 2100mV 连续 5 次）走低电量关机路径；< 2000mV 说明电源已断，必须立即保存。
- 目的：**任何时刻拔电池/掉电，档位、模式、偏移都不会丢**——保存走“强制保存”路径，不依赖 30 秒后台定时保存。

### 5.4 开机测压门控

- 无论按键开机还是调试器开机，都先测电压，**必须 > lvp_ext + 100mV（约 2.2V）才允许启动**。
- 电压不足时 LED 闪 100ms 提示并保持关机。
- 目的：防止电池接近耗尽时开机造成 LED 亮度不足/闪烁的“假启动”体验。

### 5.5 自动关机（省电）

- 40 分钟无操作调暗 → 再 10 分钟无操作关机进深睡。
- 深睡（STANDBY0）：MCU 进入最低功耗状态，仅保留按键唤醒；任意按键按下立即唤醒。
- 唤醒后自动恢复亮度并重新计时。

### 5.6 ALS 自动感光与故障处理

- ALS 模式下，红点亮度跟随环境光自动调节：环境越亮红点越亮，越暗越暗（有最低亮度 30 保底，避免全黑时红点不可见）。
- 传感器连续 **3 次**读取失败 → 进入 ALS 故障态：LED **每 1.5s 周期闪烁**提示；**10 秒后自动恢复**并切回手动模式（配置落盘）。
- 连续 3 次“故障→自恢复”后**锁定 ALS**：拒绝从手动切回 ALS，防止传感器永久损坏时反复闪烁（当前在 ALS 仍可切回手动）。

### 5.7 配置记忆与掉电保存

- 所有设置（档位、模式、ALS 偏移、电压参数等）自动保存到 Flash（NVM，双扇区多槽位、写后校验、坏槽跳过）。
- 日常调节只标记“待保存”，后台 **30 秒**自动落盘（减少 Flash 磨损）；**关机、低电量关机、掉电**时强制立即保存。
- 恢复出厂：调试器执行“恢复出厂+保存”指令；烧录后可选首次上电清空存储区（出厂配置开关）。

## 6. 常见问题（FAQ）

**Q1：灯灭了，松手又亮了？**
A：双键 1.5s 熄灯后必须**松开且未按满 5s** 才会确认关机进深睡；如果一直按到 5s 会切换 ALS/手动模式并重新亮灯。这是设计行为，防止误触关机。想关机就“按 1.5s 灭灯 → 松手”。

**Q2：怎么切换自动感光（ALS）和手动模式？**
A：运行中双键按 1.5s 灭灯后**继续按满 5s**，双闪提示后即切换并亮灯。关机状态下直接长按双键满 5s 会以 ALS 模式开机。

**Q3：ALS 模式下亮度没变化/没效果？**
A：先确认当前是 ALS 模式（双键 5s 切换）；环境光变化需要几秒平滑过渡（防抖）；若传感器故障会闪烁提示并 10s 后自动切回手动（见 5.6）。

**Q4：灯每 2 秒闪一下？**
A：低电量警示：电压连续低于 2.3V，亮度同时降到 1/4。请尽快更换电池；电压回升后自动恢复。

**Q5：为什么按开机没反应？**
A：开机前会测电压，低于约 2.2V 拒绝开机并闪 100ms。请更换电池或用稳压电源供电。

**Q6：电压低的时候为什么升不了档？**
A：自适应档位限制在起作用：电压不足时亮度上限被压低（防止 LED 过流/电池过放），此时升档可能被标记越限但亮度不增。属正常保护。

**Q7：关机后配置会丢吗？**
A：不会。关机、低电量关机、掉电都会强制保存配置到 Flash；日常调节后台 30s 自动落盘。

**Q8：电池能用多久？**
A：取决于亮度档位。LED 最大电流 2.8mA、电池 12.5mAh×2：最高亮度档连续点亮约数小时；自动调暗/关机后深睡电流极低（µA 级），待机可达数月量级。实际以测量为准。

**Q9：OFF 态 SWD 连不上调试器？**
A：普通版关机后进 STANDBY0 深睡（SWD 断开），属于正常省电行为。需要关机态可连请用 DBG 变体，或在调试器中置位 FLAG_SWD_IN_OFF_STATE。

**Q10：如何进入烧录/调试模式（FLASH 模式）？**
A：关机状态下按住 BT1 0.8s（电压达标）进入 FLASH 模式，5 分钟无操作自动复位；也可以直接用调试器烧录（会自动处理）。

**Q11：怎么恢复出厂设置？**
A：用 RMRDebugger 调试器执行“恢复出厂+保存”（系统指令 5），档位/偏移/特性标志全部恢复出厂默认并立即保存。

**Q12：红点有轻微亮度波动/闪一下？**
A：属于电压补偿在起作用时的正常现象；如果规律性闪烁请对照第 4 章指示灯速查判断是否低电量或 ALS 故障。

---

# 第二部分 技术说明书

## 7. 版本结论：特性支持确认

当前固件 **V4.3.3** 已完整支持以下特性（默认全部开启，运行时可用 NVM 标志位关闭其中一部分）：

| 特性 | 编译开关 / 运行标志 | 状态 |
|---|---|---|
| 自适应电压补偿（恒流 PWM 占空比补偿 + 电压线性降额） | FEATURE_VOLTAGE_COMPENSATION / FLAG_VOLTAGE_COMPENSATION(bit0) | 已支持 |
| 自适应档位限制（电压不足时限制档位/标记越限） | FEATURE_ADAPTIVE_GEAR_LIMIT / bit1 | 已支持 |
| 自动感光 ALS（OPT3001） | FEATURE_ALS_MODE / bit2 | 已支持 |
| ALS 亮度偏移调节（±50% 共 5 段） | FEATURE_ALS_OFFSET_ADJUST | 已支持 |
| ALS 平滑与渐变限速 | FEATURE_ALS_SMOOTHING | 已支持 |
| 无操作自动调暗 / 自动关机 | FEATURE_INACTIVITY_AUTO_DIM_OFF / bit3 | 已支持 |
| 配置记忆（NVM 双扇区多槽位） | FEATURE_MEMORY_SAVE | 已支持 |
| NVM 写后校验 + 3 槽位尝试 + 重试 + RAM 影子 | FEATURE_SAVE_VERIFY / FEATURE_SAVE_RAM_SHADOW | 已支持 |
| 低功耗 STANDBY0 深睡（WWDT 拉伸 + IOMUX 唤醒） | FEATURE_LOWPOWER_STANDBY / bit4 | 已支持 |
| LVP 低电压闪烁警告 | FEATURE_LVP_FLASH_WARNING / bit5 | 已支持 |
| OFF 态保持 SWD 可访问 | FEATURE_SWD_IN_OFF_STATE / bit6 | 已支持 |
| 上电自动开机（仅冷启动生效） | FEATURE_AUTO_POWER_ON / bit7 | 已支持 |
| ECO 动态降频 / WFI 睡眠 / 采样电源门控（省电变体） | POWER_SAVE_BUILD | 已支持（ECO_D / ECO_B） |
| 开机测压门控、掉电保存、恢复出厂、调试信箱/注入 | — | 已支持 |

> 结论：**自适应电压补偿已支持**，核心是“恒流模型”——LED 平均电流由 brt/1000 × I_max 决定，PWM 占空比按当前电压下的峰值电流实时反推；电压下降时峰值电流变小，占空比自动增大，从而维持亮度恒定。详见第 11 章。

## 8. 产品组成与硬件资料

RMR 1:2.05 主要组成部分：

- 主控：TI MSPM0C1104（Cortex-M0+，24MHz 总线时钟，1ms 硬件时基由 GPTIMER14 产生）
- 红点光源：APTD1608SECK-J4 红色 LED（Vf 约 2.2V，最大电流 2.8mA），PWM 恒流驱动
- 环境光传感器：TI OPT3001（I2C，软件模拟时序，GPIO 位操作）
- 供电：2×SR516SW 氧化银纽扣电池（标称 3.1V，12.5mAh/节，内阻约 25Ω/节）或 1.6–3.6V 可调稳压电源直连（120–635Ω 可调限流电阻）
- 操作：BT1 / BT2 两颗物理按键（低有效，8 次采样去抖）
- 调试/烧录：仅 SWD（XDS110 或 DAPLink），无 UART

| 目录 | 内容 |
|---|---|
| PCB/ | 原理图/PCB 工程（ProDoc）、Gerber 打样包、BOM 清单 |
| model/ | 结构 STEP 模型、SHAPR 工程、镜片设计 |
| image/ | 产品渲染图 15 张 |
| firmware/RMR/ | 固件工程（CCS 21） |
| firmware/RMRDebugger/ | 桌面调试器源码（Qt 6） |
| RMR_Factory_Tool_V2.0/ | 打包版调试工具（免编译：rmrdebuger.exe + openocd.exe） |

## 9. 固件版本与变体

V4.3.3 由 app_config.h 中 4 个编译宏组合出 6 个变体：

| 变体 | 版本串 | 宏配置 | 适用场景 |
|---|---|---|---|
| DIRECT | V4.3.3_DIRECT | 默认（POWER_SOURCE_DIRECT=1） | 稳压电源直连（不算电池内阻），普通版 |
| BATT | V4.3.3_BATT | POWER_SOURCE_DIRECT=0 | 2×SR516SW 电池，r_series 含 2×25Ω 内阻 |
| ECO_D | V4.3.3_ECO_D | POWER_SAVE_BUILD=1 + DIRECT | 直连省电版 |
| ECO_B | V4.3.3_ECO_B | POWER_SAVE_BUILD=1 + BATT | 电池省电版 |
| DBG | V4.3.3_DBG | DEBUG_BUILD=1 | 测试板专用，全程 SWD 保活 |
| DBGL | V4.3.3_DBGL | DEBUG_LP_BUILD=1 | 低功耗调试版：OFF 态深睡、运行态 SWD |

编译产物：firmware/RMR/hex/（6 个 hex）；firmware/RMR.hex 为发布镜像。

## 10. 系统状态机

```
                    +------ 双键 1.5s（测压达标）------+
SYS_OFF <-----------+                                v
   ^                |                          SYS_RUN -> SYS_LVP_CRIT（连续 5 次 <2300mV）
   | 双键1.5s熄灯    |                                |  ^
   | (松开<5s进STANDBY0)  v                          |  | 电压回升+迟滞
   |             SYS_FLASH_MODE（单键BT1 0.8s进入，5min超时复位）|
   |                  |                              v  |
   +------------------+---- 双键 1.5s 测压开机 <------+--+
                                              ^
   SYS_ALS_ERR --10s 自恢复--> SYS_RUN（切回手动并落盘）
        ^
        +-- ALS 连续 3 次读取失败（闪烁提示，1.5s 周期）

   SYS_TEST_MODE（调试器授权进入）--> 正常退出 = SYS_FLASH_MODE；授权丢失 = 复位
```

- SYS_OFF：LED 全灭；默认版本若未置位“OFF 态 SWD”标志则进入 STANDBY0 深睡
- SYS_RUN：正常运行（手动/ALS 亮度控制）
- SYS_LVP_CRIT：低电压临界，LED 每 2s 闪 50ms 且亮度降为 1/4 警示
- SYS_FLASH_MODE：烧录/调试模式（VCC_EN 拉高、NRST 恢复、SWD 可连），5min 无操作自动复位
- SYS_ALS_ERR：ALS 故障，LED 以 1.5s 周期闪烁（亮 600ms），10s 后自恢复
- SYS_TEST_MODE：调试器授权后进入，支持注入与系统命令

## 11. 亮度控制与自适应电压补偿（核心算法）

### 11.1 亮度标度

- 逻辑亮度 brt：0-1000（1000 = 满亮）
- 物理 PWM 寄存器：0-2399（PWM_REG_MAX），CC=2399 表示占空比 0（灭）

### 11.2 恒流 PWM 补偿（battery_brt_to_pwm）

```text
目标平均电流   i_req = brt / 1000 x I_max            （I_max = 2.8mA 默认）
峰值电流       i_peak = (Vbatt - Vf) / R_total       （Vf = 2.2V）
占空比         duty  = i_req / i_peak（上限 100%）
PWM 装载值      CC = 2399 - duty x 2399 / 1000
```

电压下降 -> i_peak 变小 -> duty 自动上升 -> 亮度维持。这就是自适应电压补偿：不靠查表，完全由恒流模型实时反推。

### 11.3 动态内阻模型（R_total = R_series + R_dyn）

```text
R_dyn = R_DYNAMIC_BASE_MOHM(50mΩ)
      + (Vbatt <= 1900mV ? 300Ω 固定
         : min( 5x10^7 / (Vbatt - 1900mV), 250Ω ))
R_series = NVM 可校准（DIRECT 默认 360Ω；BATT 默认 360Ω + 2x25Ω）
```

### 11.4 五重安全限制（battery_get_safe_brt，取最小值）

| 限制 | 依据 | 说明 |
|---|---|---|
| limit_i_led | 峰值电流 <= i_max_ua(2.8mA) | 防止 LED 过流 |
| limit_v_drop | 压降后电压 >= WALL_MIN_V_BATT_MV(2400mV) | 电池电压“墙”，保底亮度 30 |
| limit_i_brt | 总放电电流 <= BATT_MAX_DISCHARGE_UA(4mA) | 限制电池总放电 |
| limit_p_avg | 总功率 <= BATT_MAX_DISCHARGE_UW(9mW) | 限制电池总功耗 |
| limit_v_derate | 电压 >=3300mV 无降额；线性降至 2400mV 时保底 30 | 电压线性降额 |

压降模型：v_drop_peak = i_peak x R_dyn x 30%（导通等效），v_drop_avg = i_peak x brt x R_dyn（平均）。
最终输出 safe_brt = min(req_brt, 各限制值)；所有中间量（g_safe_brt_out、g_limit_*、g_dyn_r_mohm、g_est_i_peak_ua）实时镜像到调试信箱，可在 RMRDebugger 中观察是哪一重限制在起作用。

### 11.5 档位自适应（FEATURE_ADAPTIVE_GEAR_LIMIT）

- 升档时若目标档 brt <= max_brt（安全上限）则正常升档
- 目标档超限但差值 <= SNAP_THRESHOLD_BRT(50) 也正常升档
- 明显越限 -> 仍升档但置 g_is_overshot（调试器可读，用于识别“电压不够高”）
- 降档时若当前档已越限 -> 连续回退到安全档

## 12. ALS 自动感光（算法细节）

### 12.1 曲线

```text
brt = ALS_SQRT_FACTOR(5) x sqrt(lux_count / 100)     （lux_count 为 OPT3001 结果寄存器计数）
     x (1 + 偏移%)                                    （5 段：+/-50/30/0%）
下限 = als_min_brt(30) ｜ 低照度上限 600 ｜ 高照度上限 800 ｜ 总上限 1000
```

分界：lux_count <= 1,000,000 用低照度上限 600，更高用 800。

### 12.2 平滑与限速（FEATURE_ALS_SMOOTHING）

- 指数移动平均（1/8 权重）
- 上升限速分档：低亮度每 tick +2、中亮度 +5、其他 +20；下降限速 -20
- 轮询周期：普通版 120ms，ECO 版 1s

### 12.3 故障处理

- 连续 3 次读取失败 -> SYS_ALS_ERR：LED 以 1.5s 周期闪烁（亮 600ms）提示
- 10s 后自恢复：关闭 ALS 切回手动模式并落盘
- 连续 3 次“故障->自恢复”后锁定 ALS（拒绝从手动切回 ALS，避免传感器永久损坏时的闪烁循环；当前在 ALS 时仍可切回手动）

## 13. 电源管理与保护（技术细节）

### 13.1 运行功耗控制

- LED 恒流驱动，电流由档位决定（0-2.8mA）
- ADC/VREF：普通版每 100ms 采样（ECO 版 500ms，采样前后开关电源域）
- ECO 版：主循环 WFI 睡眠替代 24MHz 忙等；OFF/FLASH 态 SYSOSC 降到 4MHz（GPTIMER14 同步重配，tick 恒为 1ms）；PWM 亮度不变时不重算不写寄存器；OFF 态 OPT3001 shutdown（0.4uA）

### 13.2 关机与深睡（STANDBY0）

- 双键 1.5s 熄灯 + 松开确认 -> SYS_OFF -> STANDBY0 深睡
- 深睡准备：WWDT 周期先拉伸再重启（约 8192s，防止 500ms 看门狗深睡复位）；IOMUX WCOMP 匹配低电平（按下即异步唤醒）+ GPIO 边沿中断双保险；受控 __disable_irq()/WFI
- 唤醒后：恢复 500ms 看门狗、禁用唤醒源、重新测压
- FLAG_SWD_IN_OFF_STATE(bit6)：置位则 OFF 态跳过深睡保持 SWD 可连（DBG 版出厂默认置位；ECO/DBGL 出厂默认清零）

### 13.3 无操作超时

- 40 分钟无操作 -> 调暗到 DIM_LEVEL(5)
- 再 10 分钟无操作 -> 自动关机
- 按键任意事件/调暗后按键 -> 立即恢复并清零计时

### 13.4 低压保护（LVP）

| 阈值 | 去抖 | 动作 |
|---|---|---|
| < lvp_crit(2300mV) | 连续 5 次 | SYS_LVP_CRIT：LED 每 2s 闪 50ms、亮度降 1/4 警示 |
| < lvp_ext(2100mV) | 连续 5 次 | 直接关机并保存配置 |
| < 2000mV（快速掉电） | 单次即触发 | 瞬间断 PWM + 立即保存 -> SHUTDOWN（DBG/DBGL 版不 SHUTDOWN，仅存配置保 SWD） |

- 开机测压门控：battery_startup_check() 必须测得电压 > lvp_ext + 100mV 才允许开机
- SYS_LVP_CRIT 回升自动恢复：电压 >= lvp_crit + 100mV 回 SYS_RUN

### 13.5 冷启动判定（AUTO_POWER_ON）

仅冷启动（RSTCAUSE = POR/BOR/SHUTDOWN 退出，或 SRAM g_por_magic 兜底）才执行自动开机；WWDT/SYSRST/调试复位一律保持关机——保证“1.5s 熄灯后不会被看门狗复位点亮”。

## 14. 配置记忆（NVM）

### 14.1 存储布局

- 记录大小固定 64 字节（编译期 _Static_assert），尾部 4 字节 FNV1a-32 CRC
- 存储区：扇区 A（0x3800）/ 扇区 B（0x3C00），各 1KB = 16 槽，双扇区轮转
- 加载：扫描全部槽位，取 CRC 合法且 seq_id 最大者；坏槽标记跳过
- 保存：槽位轮转 + 3 槽位尝试；写后回读校验 + 擦写耗时补偿；失败 3 次放弃本次（保留 RAM 影子与 dirty，后续重试最多 5 次）
- 后台 30s 自动保存（仅 RUN 态）；关机/LVP/掉电路径强制保存

### 14.2 可配置项（NVM 字段）

| 字段 | 默认值 | 说明 |
|---|---|---|
| params | lvl=4, ALS=0, offs=2 | 档位 0-8 ｜ ALS 使能 ｜ 偏移索引 0-4 |
| features | 8 位标志 | 运行时特性开关（受编译期 mask 过滤） |
| r_base | 50 mΩ | 动态内阻基数 |
| r_series | 360000 / 410000 mΩ | 串联限流电阻（电池版含 2x25Ω 内阻，可校准） |
| v_led_fw | 2200 mV | LED 正向压降 |
| i_max_ua | 2800 uA | LED 最大电流 |
| batt_p_uw | 9000 uW | 电池最大放电功率 |
| als_min_brt | 30 | ALS 最低亮度 |
| lvp_crit | 2300 mV | 低压临界 |
| lvp_ext | 2100 mV | 低压极值（关机） |
| als_sqrt_factor | 5 | ALS 曲线系数（0=用默认，NVM 1-20） |
| als_cap_low_x100 / als_cap_high_x100 | 6 / 8 | ALS 低/高照度亮度上限（0=用默认） |
| default_level | 4 | 出厂档位 |
| seq_id | — | 序列号（磨损均衡） |

### 14.3 恢复出厂

- 烧录后首次上电可选清空存储区（DEV_CLEAR_NVM_ON_POR=1）
- 调试器指令 5：恢复出厂 + 立即保存
- 出厂默认值宏在 app_config.h [0] 段，可编译期修改

## 15. 调试接口（RMRDebugger / 调试信箱 / IPC）

### 15.1 调试信箱（g_test_box，SWD 直接读 RAM）

- 授权：magic=0x54455354 + host_version 匹配；授权丢失 -> 复位；正常退出 -> SYS_FLASH_MODE
- 实时监视（每 tick 刷新）：电压（原始/滤波）、估算电流/功率/硬件功率、动态内阻、亮度/PWM、五重限制值、ALS 原始/滤波/传感器状态/错误计数、档位/偏移/模式、NVM 状态、复位原因、无操作秒数等
- 系统命令：2=复位 ｜ 3=写配置（mask 过滤）｜ 4=保存 ｜ 5=恢复出厂+保存 ｜ 6=开机（测压）｜ 7=关机
- 注入：模拟按键（+/-）、ALS 注入（开关+lux）、LED 注入（1=PWM 直驱 2=无限制亮度 3=受限亮度）、拦截物理按键
- 实时诊断：TEST 态每 tick 刷新计算数据（battery_get_safe_brt 全链路）

### 15.2 RMRDebugger（Qt 6）

- XDS110/DAPLink 自动扫描（OpenOCD SWD，5kHz-4MHz）
- 实时遥测：电压/电流/功率/内阻/档位/亮度/PWM/ALS/NVM 全字段 + 三张图表（10s 滚动窗口、Y 轴自适应）
- 一键烧录：擦除+编程+校验+复位；连接失败自动清理残留 OpenOCD 进程
- 测试模式：解锁/读配置/写配置/保存/恢复出厂/开关机/软复位
- 虚拟按键与真实按键语义一致；状态与操作合并显示
- Power-Z KM003C 电压电流计接入（HID，200ms 轮询，10s 滑动窗口平均）
- 隐藏 IPC：127.0.0.1:7345，JSON 行协议（ping/state/scan/setfw/flash/unlock/syscmd/cmd/write/read/poll/speed/key/power/led/als）

## 16. 编译与烧录

### 16.1 编译（CCS 21）

- 打开工程 firmware/RMR/（.ccsproject，tiarmclang 工具链）
- 切换变体：修改 app_config.h 顶部 POWER_SOURCE_DIRECT / POWER_SAVE_BUILD / DEBUG_BUILD / DEBUG_LP_BUILD
- post-build 步骤：tiarmobjcopy 生成 Intel HEX（根治 tiarmhex 版本段 bug）

### 16.2 烧录

方式 A（推荐）：RMRDebugger GUI 一键烧录（自动 halt + flash probe + program verify reset，烧录后清 SRAM 开机门控模拟冷启动）。

方式 B（OpenOCD 命令行）：

```bat
openocd -s <openocd>\scripts -f interface/xds110.cfg -f target/ti_mspm0.cfg ^
  -c "transport select swd" -c "adapter speed 1000" ^
  -c "tcl_port 3334" -c "gdb_port disabled" -c "telnet_port disabled"
```

## 17. 修订记录

| 版本 | 日期 | 内容 |
|---|---|---|
| V4.3.3 | 2026-08 | 双键关机确认机制（灭灯不等于 standby）；深睡唤醒根因修复（WWDT 拉伸顺序/WCOMP 方向/冷启动门控）；调试版 DBG/DBGL；ECO 动态降频；NVM 延迟保存；ALS 故障锁定；RMRDebugger 烧录/遥测完善 |
| V4.3.2 | — | 虚拟按键与真实按键一致；调试器连接自动清理；IPC 完善 |
| V4.3.1 | — | 双版本（DIRECT/BATT）；1ms 硬件时基 GPTIMER14；电压降额+PWM 补偿根因修复；tiarmobjcopy 生成 HEX |

---

本文档对应仓库 tiny-rmr-1-2.05；固件源码见 firmware/RMR/，调试器见 firmware/RMRDebugger/。

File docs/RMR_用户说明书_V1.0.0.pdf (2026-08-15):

R M R S E R I E S

# RMR 1:2.05

## 微 型 反 射 式 红 点 瞄 准 镜

用户说明书
版本 V1.0.0

L E D 红 点 · 自 动 感 光 · 超 低 功 耗

2 0 2 6 - 0 8 - 1 5

RMR 1:2.05 用户说明书 · V1.0.0

第 1 页 / 共 6 页

目录

### 1 产品简介

### 2 产品组成

### 3 安装与供电

### 4 开机与关机

### 5 亮度调节（手动模式）

### 6 自动感光模式

### 7 自动调暗与自动关机

### 8 低电量提示与保护

### 9 技术参数

### 10 故障排除

### 11 注意事项与维护

### 12 版本记录

第 2 页 / 共 6 页

## 1 产品简介

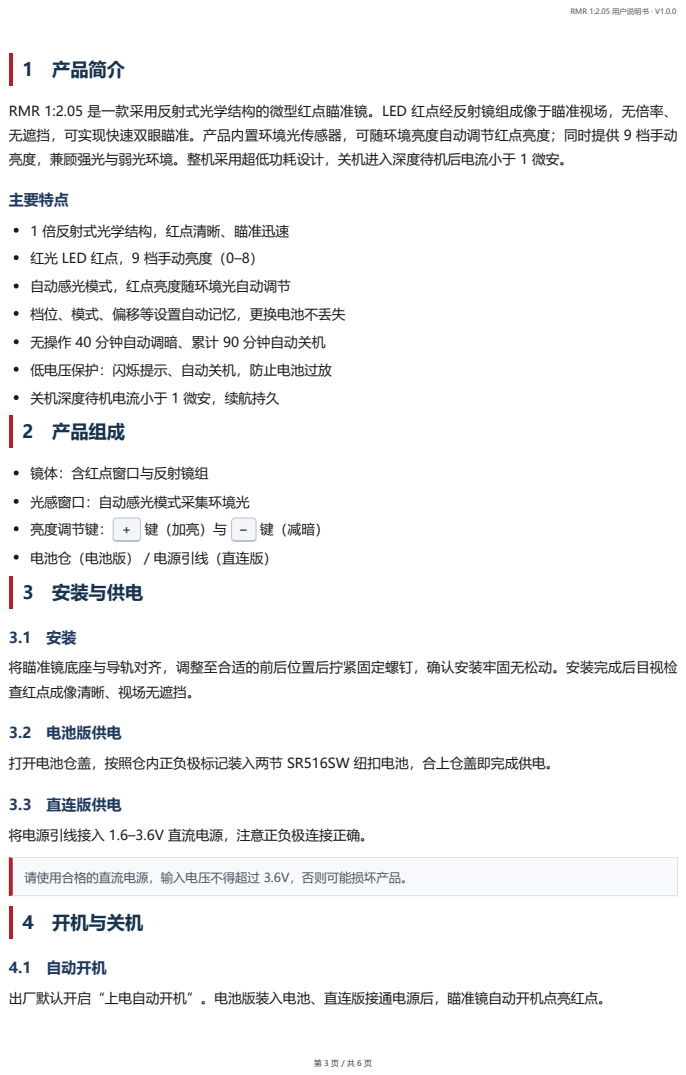
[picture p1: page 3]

RMR 1:2.05 是一款采用反射式光学结构的微型红点瞄准镜。LED 红点经反射镜组成像于瞄准视场，无倍率、
无遮挡，可实现快速双眼瞄准。产品内置环境光传感器，可随环境亮度自动调节红点亮度；同时提供 9 档手动
亮度，兼顾强光与弱光环境。整机采用超低功耗设计，关机进入深度待机后电流小于 1 微安。

主要特点
1 倍反射式光学结构，红点清晰、瞄准迅速
红光 LED 红点，9 档手动亮度（0–8）
自动感光模式，红点亮度随环境光自动调节
档位、模式、偏移等设置自动记忆，更换电池不丢失
无操作 40 分钟自动调暗、累计 90 分钟自动关机
低电压保护：闪烁提示、自动关机，防止电池过放
关机深度待机电流小于 1 微安，续航持久
2 产品组成

镜体：含红点窗口与反射镜组
光感窗口：自动感光模式采集环境光
亮度调节键： ＋ 键（加亮）与 − 键（减暗）
电池仓（电池版）／电源引线（直连版）
3 安装与供电

将瞄准镜底座与导轨对齐，调整至合适的前后位置后拧紧固定螺钉，确认安装牢固无松动。安装完成后目视检
查红点成像清晰、视场无遮挡。

3.2 电池版供电
打开电池仓盖，按照仓内正负极标记装入两节 SR516SW 纽扣电池，合上仓盖即完成供电。

3.3 直连版供电
将电源引线接入 1.6–3.6V 直流电源，注意正负极连接正确。

请使用合格的直流电源，输入电压不得超过 3.6V，否则可能损坏产品。
4 开机与关机

4.1 自动开机
出厂默认开启“上电自动开机”。电池版装入电池、直连版接通电源后，瞄准镜自动开机点亮红点。

### 4.2 手动开机

操作 | 关机状态下，同时按住 ＋ 与 − 两键约 1.5 秒，红点亮起即开机。

供电电压过低（低于约 2.2V）时产品将拒绝开机，红点短闪一次提示，请更换电池或检查电源。

### 4.3 关机

操作 | 开机状态下，同时按住两键约 1.5 秒，红点熄灭后松开两键，即进入关机（深度待机）状态。

红点熄灭后若继续按住两键不放，满 5 秒时将切换“手动 / 自动感光”模式并重新点亮，不会关机。

### 4.4 快捷开机

关机状态下，同时按住两键满 5 秒，可直接以“自动感光”模式开机。

## 5 亮度调节（手动模式）

加亮 | 短按 ＋ 键，亮度加一档。
减暗 | 短按 − 键，亮度减一档。

手动模式共 9 档亮度（0–8），出厂默认第 4 档。每次按键红点亮度即时变化，设置自动保存，下次开机保持 上次档位。

## 6 自动感光模式

### 6.1 模式切换

开机状态下，同时按住两键满 5 秒，红点闪烁两次，在“手动模式”与“自动感光模式”之间切换，当前模式 自动保存。

### 6.2 自动感光

自动感光模式下，红点亮度由环境光传感器实时调节：环境暗则自动变暗，环境亮则自动变亮，保证红点清晰 可见且不刺眼。

### 6.3 亮度偏移

自动感光模式下，短按 ＋ / − 键可调节整体亮度偏移（0–4 档，出厂默认第 2 档）。弱光环境建议调低偏 移，强光环境建议调高偏移，偏移值自动保存。

### 6.4 故障保护

若光感传感器异常，红点将以约 1.5 秒周期闪烁提示，10 秒后自动退回手动模式；连续多次故障后将锁定在手 动模式，避免反复提示干扰使用。

## 7 自动调暗与自动关机

开机后 40 分钟内无任何按键操作，红点自动调暗至最低亮度，以节省电能。

第 4 页 / 共 6 页

调暗后继续无操作 50 分钟（累计 90 分钟），产品自动关机。 任意按键操作将重置计时并恢复红点亮度。

## 8 低电量提示与保护

供电电压低于约 2.3V 时：进入低电量保护状态，红点亮度自动降低，并以约 2 秒周期短闪提示，请及时更 换电池或补充供电。
供电电压低于约 2.1V 时：产品自动关机，防止电池过放损坏。
更换电池或电压恢复到约 2.4V 以上后，即可正常开机使用。 掉电保护：使用中电源突然中断时，产品会立即保存当前设置，设置不丢失。

## 9 技术参数

项目 | 参数
产品型号 | RMR 1:2.05
光学结构 | 1 倍反射式红点
红点光源 | 红光 LED（正向电压约 2.2V，最大电流 2.8mA）
亮度 | 手动 9 档（0–8）＋ 自动感光（偏移 0–4）
供电（电池版） | 2 × SR516SW 氧化银纽扣电池（新电池约 3.1V）
供电（直连版） | 1.6–3.6V 直流
工作电流 | 最大约 4mA
待机电流 | 小于 1µA（深度待机）
低电压提示 | 约 2.3V
低压自动关机 | 约 2.1V
自动调暗 | 40 分钟无操作
自动关机 | 累计 90 分钟无操作（调暗后 50 分钟）

## 10 故障排除

第 5 页 / 共 6 页

现象 | 处理方法
红点不亮、无法开机 | 检查电池是否装入且电量充足；直连版检查电源电压（需高于约 2.2V）；确认操作为同时按住两键约 1.5 秒。
红点每 2 秒短闪 | 低电量提示，请更换电池或补充供电。
红点以 1.5 秒周期闪烁 | 光感传感器异常提示，10 秒后自动退回手动模式；若反复出现请联系 售后。
亮度不随环境变化 | 确认当前处于“自动感光”模式（双键按住满 5 秒切换）。
无法开机但红点短闪一次 | 供电电压不足（低于约 2.2V），请更换电池或检查电源。

## 11 注意事项与维护

请勿直视红点光源，避免强光直射眼睛。
电池请按正负极方向正确安装；长期不使用请取出电池（电池版）。 直连版请使用 1.6–3.6V 直流电源，过高电压会损坏产品。 避免强烈撞击、跌落与挤压，请勿自行拆解或改装。
清洁光学窗口时请使用干净软布轻轻擦拭，避免划伤；请勿使用有机溶剂。 请勿将产品长时间置于高温、高湿或阳光暴晒环境。
本说明书以 V1.0.0 固件功能为准，后续更新恕不另行通知。

## 12 版本记录

版本 | 日期 | 说明
V1.0.0 | 2026-08-15 | 首版发布

第 6 页 / 共 6 页

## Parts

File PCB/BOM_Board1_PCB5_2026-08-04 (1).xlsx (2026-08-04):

No. | Quantity | Comment | Designator | Footprint | Value | Manufacturer Part | Manufacturer | Supplier Part | Supplier | Category
1 | 1 | 10nF | C2 | C0201 | 10nF | GRM033R71E103KE14D | muRata(村田) | C85930 | LCSC | 电容:贴片电容(MLCC)
2 | 4 | 100nF | C1,C3,C5,C13 | C0201 | 100nF | GRM033R61E104KE14D | muRata(村田) | C76939 | LCSC | 电容:贴片电容(MLCC)
3 | 7 | 4.7uF | C6,C7,C8,C9,C10,C11,C12 | C0402 | 4.7uF | GRM155R61C475ME15D | muRata(村田) | C913526 | LCSC | 电容:贴片电容(MLCC)
4 | 1 | 10uF | C4 | C0402 | 10uF | GRM155R61A106ME11D | muRata(村田) | C408132 | LCSC | 电容:贴片电容(MLCC)
5 | 1 | WAFER-SH1.0-2PWB | U? | CONN-SMD_2P-P1.00_XUNPU_WAFER-SH1.0-2PWB |  | WAFER-SH1.0-2PWB | XUNPU(讯普) | C3029341 | LCSC | 连接器:线对板针座
6 | 1 | X6511FRS-05-C85D30 | H? | HDR-SMD_5P-P2.54-H-F_X6511FRS-19-C85D30 |  | X6511FRS-05-C85D30 | XKB Connection(中国星坤) | C5142238 | LCSC | 连接器:排母
7 | 1 | APT1608SECK/J4-PRV | U5 | LED0603-RD |  | APT1608SECK/J4-PRV | Kingbright(今台) | C5879376 | LCSC | 光电器件:发光二极管/LED
8 | 2 | 10kΩ | R2,R3 | R0201 | 10kΩ | 0201WMF1002TEE | UNI-ROYAL(厚声) | C473048 | LCSC | 电阻:贴片电阻
9 | 1 | 10kΩ | R5 | R0201 | 10kΩ | RC0201FR-0710KL | YAGEO(国巨) | C106225 | LCSC | 电阻:贴片电阻
10 | 1 | 40kΩ | R1 | R0201 | 40kΩ | TNPW020140K0DEED | VISHAY(威世) | C1857691 | LCSC | 电阻:贴片电阻
11 | 1 | 100Ω | R4 | R0402 | 100Ω | FRC0402F1000TS | FOJAN(富捷) | C2906860 | LCSC | 电阻:贴片电阻
12 | 1 | 390Ω | R4 | R0402 | 390Ω | FRC0402F3900TS | FOJAN(富捷) | C2909353 | LCSC | 电阻:贴片电阻
13 | 1 | 300Ω | R? | RES-ADJ-SMD_3P-L3.8-W3.7_VGF39NCHXT | 300Ω | VGF39NCHXT-B301 | HDK(北陆电气) | C22461623 | LCSC | 电阻:可调电阻/电位器
14 | 2 | H5VL10B | D1,D2 | SOD-882_L1.0-W0.6-BI |  | H5VL10B | R+O(宏嘉诚) | C7420372 | LCSC | 三极管/MOS管/晶体管:静电和浪涌保护(TVS/ESD)
15 | 2 | TS2306A 200gf 002 | U1,U4 | SW-SMD_L3.0-W2.0-LS3.5 |  | TS2306A 200gf 002 | SHOU HAN(首韩) | C5363482 | LCSC | 按键/开关:轻触开关
16 | 1 | MSPM0C1104SRUKR | U2 | WQFN-20_L3.0-W3.0-P0.40-TL-EP1.7 |  | MSPM0C1104SRUKR | TI(德州仪器) | C20608323 | LCSC | 单片机/微控制器:单片机(MCU/MPU/SOC)
17 | 1 | OPT3001IDNPRQ1 | U3 | WSON-6_L2.0-W2.0-P0.65-BL-EP |  | OPT3001IDNPRQ1 | TI(德州仪器) | C2861428 | LCSC | 传感器:环境光传感器
18 | 1 | SP2231NC | Q1 | X2-DFN1006-3_L1.0-W0.6-BR |  | SP2231NC | Siliup(矽普) | C41355154 | LCSC | 三极管/MOS管/晶体管:场效应管(MOSFET)

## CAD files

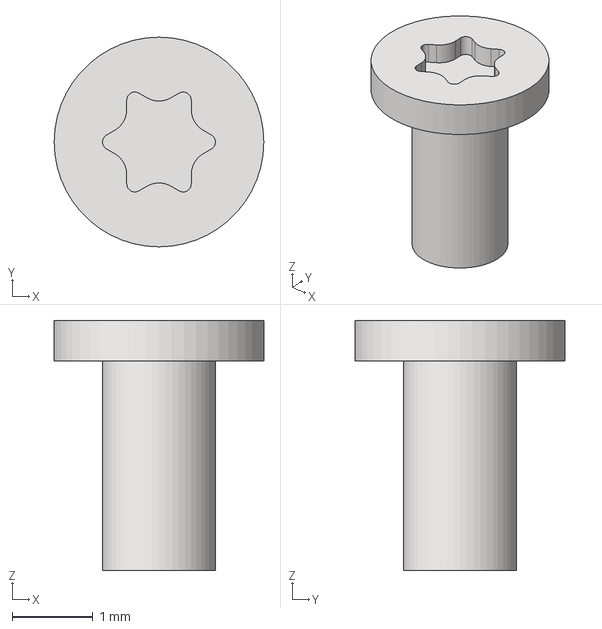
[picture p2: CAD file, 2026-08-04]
model/fix_step/螺丝占位_3.step
2.60 x 2.60 x 3.10 mm

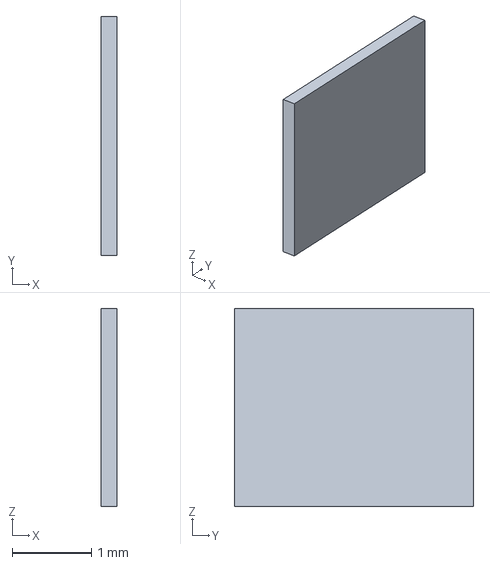
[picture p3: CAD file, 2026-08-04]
model/fix_step/保护玻璃.step
0.2 x 3.01 x 2.50 mm

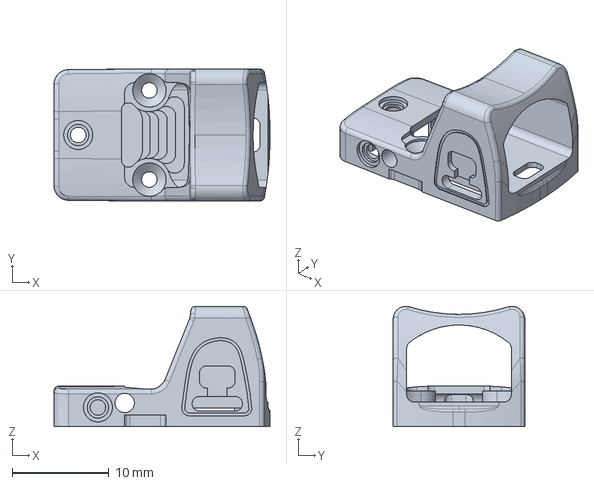
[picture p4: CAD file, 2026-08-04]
model/fix_step/主体-铸造.step
22.3 x 13.6 x 12.4 mm

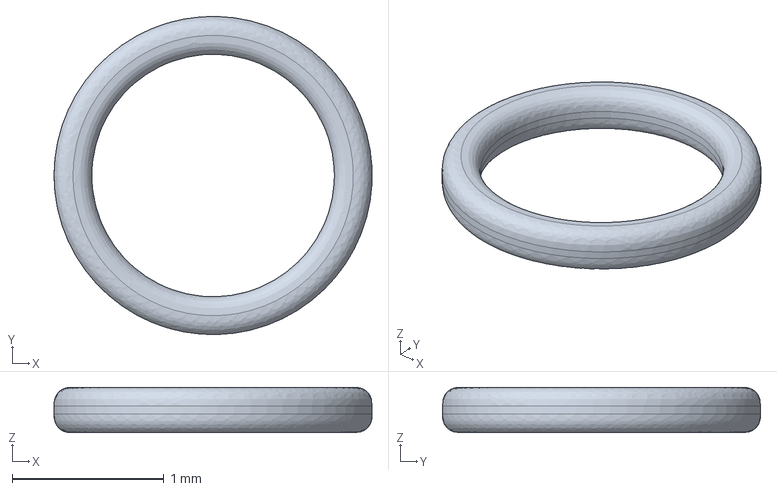
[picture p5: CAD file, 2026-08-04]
model/fix_step/1.2_0.4.step
2.10 x 2.10 x 0.3 mm

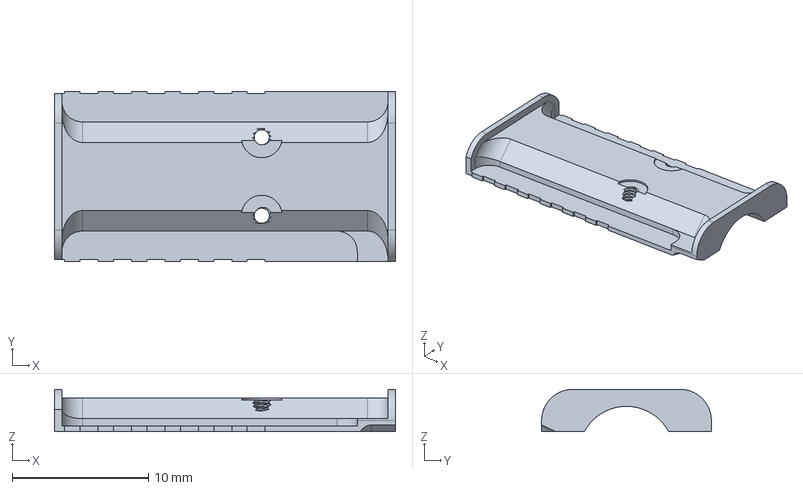
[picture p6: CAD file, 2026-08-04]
model/fix_step/cnc滑架 mos 钢制.step
25.0 x 12.5 x 3.11 mm

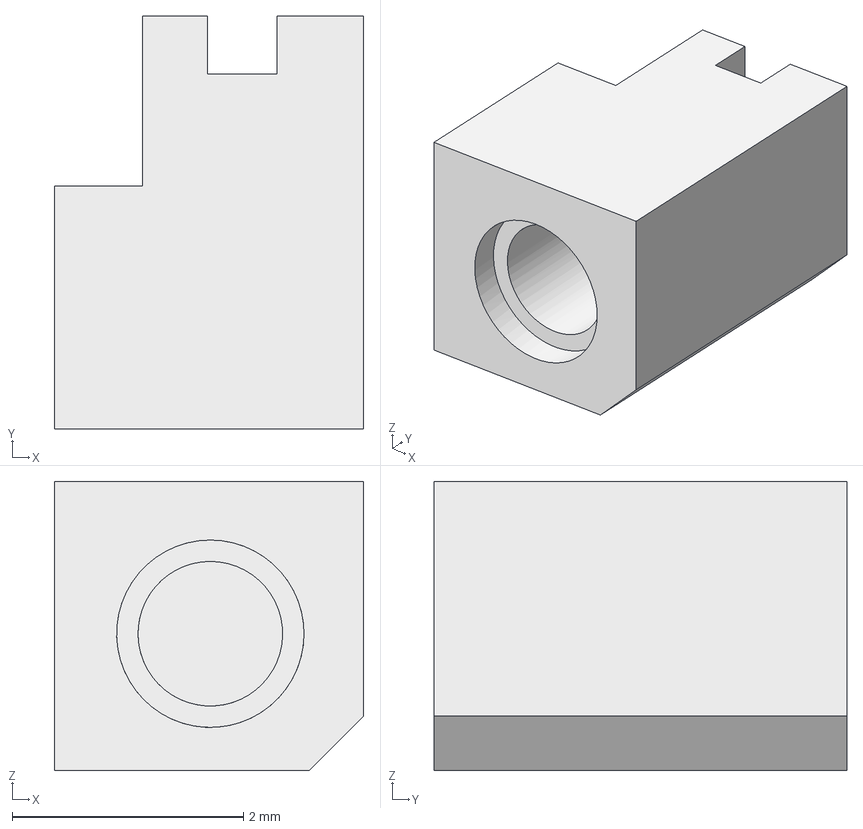
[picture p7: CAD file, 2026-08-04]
model/fix_step/主動夾臂 (偏置 无实体螺纹).step
2.67 x 3.57 x 2.50 mm

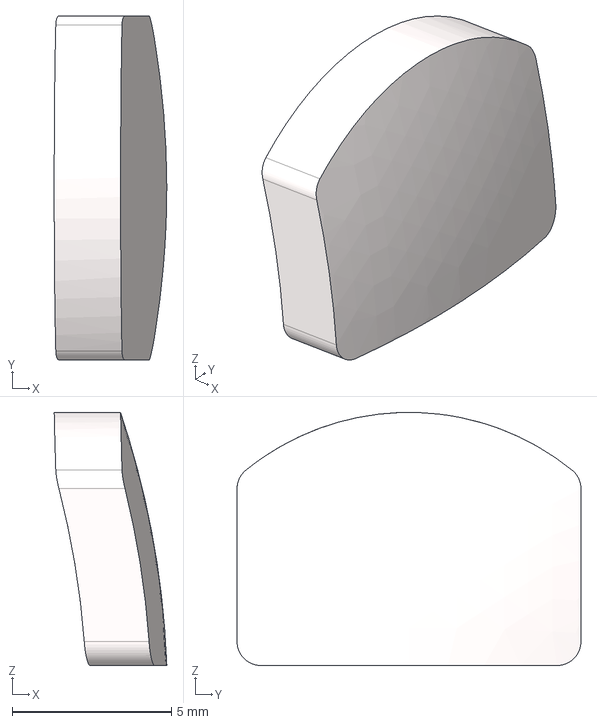
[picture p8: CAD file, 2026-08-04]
model/fix_step/RMR_V1_C_1.585_30.step
3.54 x 10.8 x 7.95 mm

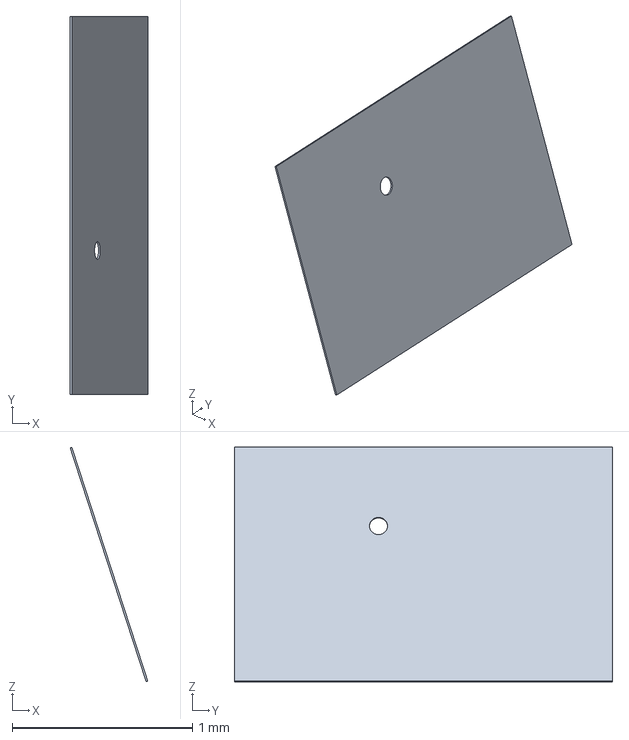
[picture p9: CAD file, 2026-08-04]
model/fix_step/挡片.step
0.432 x 2.10 x 1.30 mm

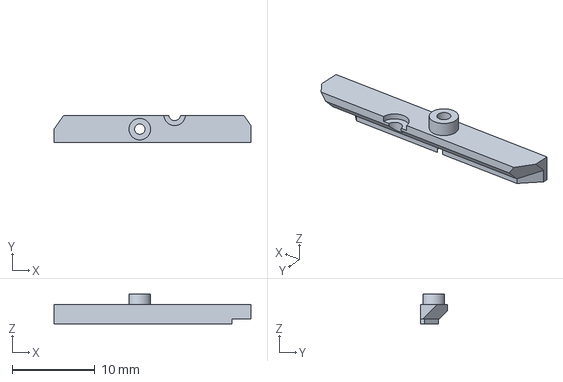
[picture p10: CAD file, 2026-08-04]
model/fix_step/钢17转接板-右（无实体螺纹）.step
23.8 x 3.27 x 3.58 mm

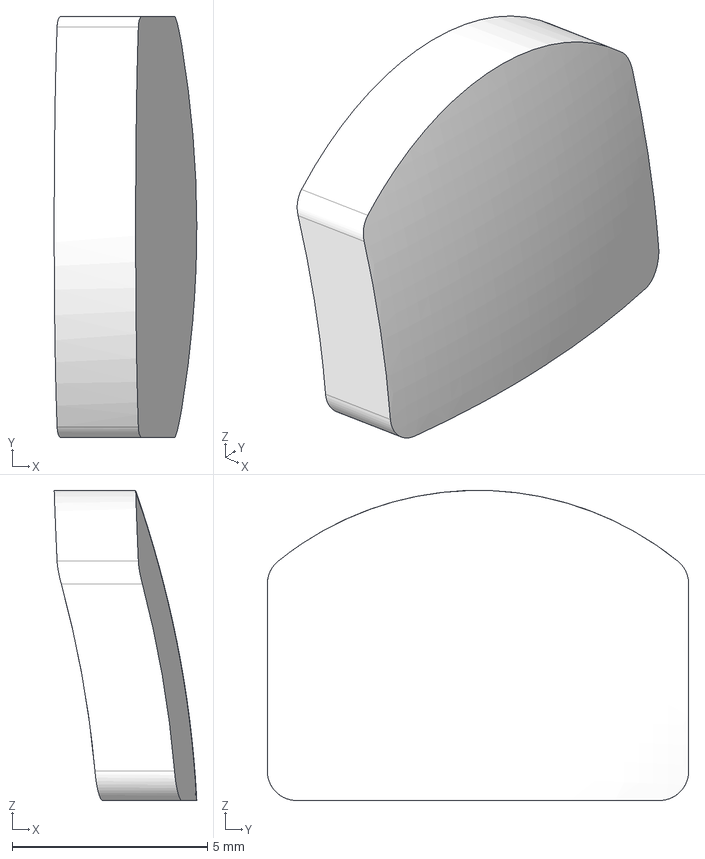
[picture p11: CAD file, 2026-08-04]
model/fix_step/RMR_V1_C_ZEONEX-K26R_1.535_56.step
3.66 x 10.8 x 7.95 mm

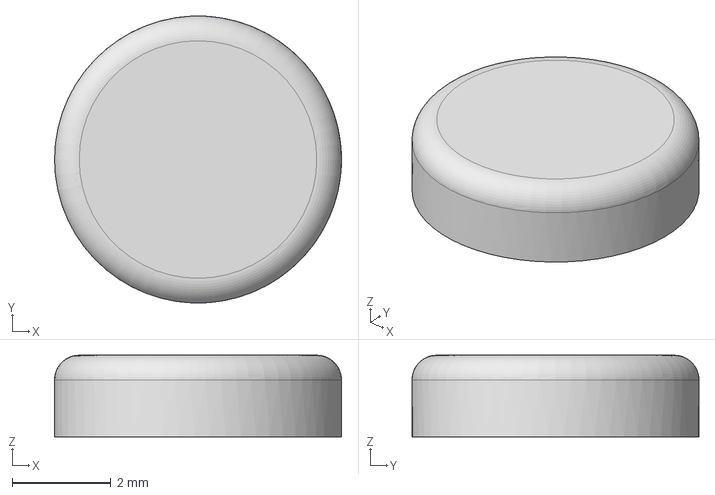
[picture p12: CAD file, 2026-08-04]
model/fix_step/電池佔位.step
5.80 x 5.80 x 1.65 mm

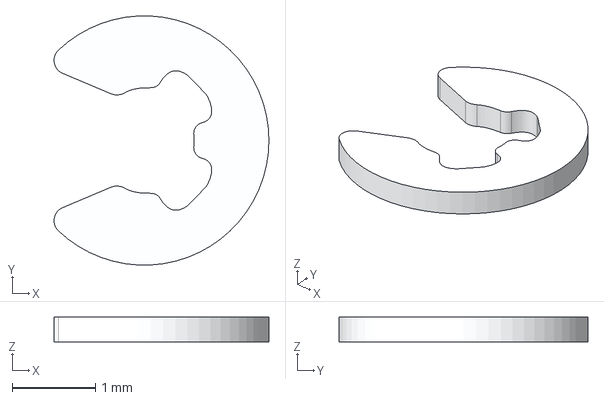
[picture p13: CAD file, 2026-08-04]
model/fix_step/卡黃.step
2.59 x 3.00 x 0.3 mm

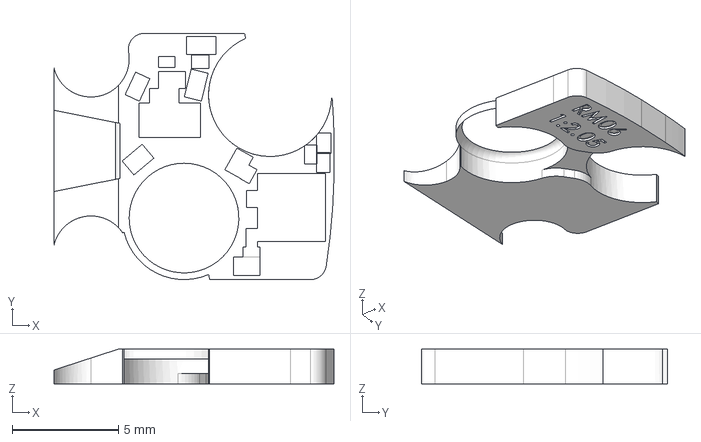
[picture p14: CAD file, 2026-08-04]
model/fix_step/电池固定框架.step
13.2 x 11.6 x 1.64 mm

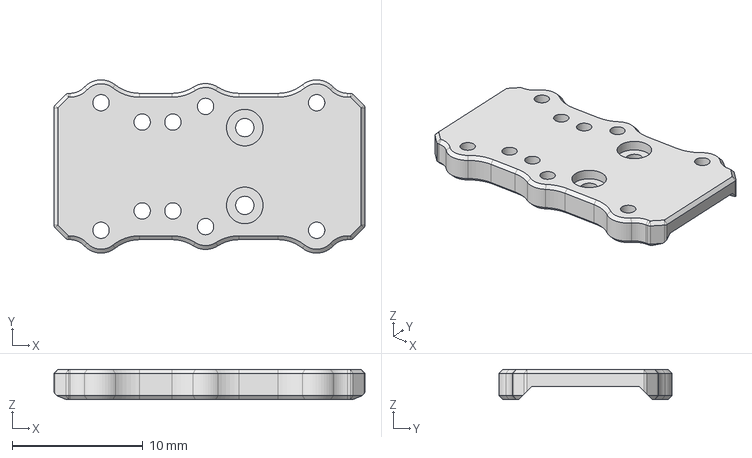
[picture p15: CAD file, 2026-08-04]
model/fix_step/转接板 m1.6 CNC.step
23.8 x 13.3 x 2.30 mm

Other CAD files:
model/fix_step/螺丝占位_2.step
model/fix_step/Y螺絲.step
model/fix_step/從夾臂 (无实体螺纹).step
model/fix_step/密封圈.step
model/2026842084480932006772738.step
model/fix_step/+.step
model/fix_step/-.step
model/fix_step/1.2_0.4_2.step
model/fix_step/BTN.step
model/fix_step/BTN_2.step
model/fix_step/FPC.step
model/fix_step/RMR_V1_C_1.56_50.step
model/fix_step/X螺絲.step
model/fix_step/fpc-b.step
model/fix_step/m1.2_2.step
model/fix_step/m1.2_2_2.step
model/fix_step/主体-cnc.step
model/fix_step/主体-org（保留）.step
model/fix_step/主動夾臂 (偏置).step
model/fix_step/主動夾臂 (含螺纹-居中).step
model/fix_step/主動夾臂 (无螺纹-居中).step
model/fix_step/主動夾臂.step
model/fix_step/卡黃_2.step
model/fix_step/彈簧.step
model/fix_step/從夾臂.step
model/fix_step/结构盖板.step
model/fix_step/螺丝占位.step
model/fix_step/螺丝占位_4.step
model/fix_step/載台.step
model/fix_step/輔助夾臂 (偏置).step
model/fix_step/輔助夾臂 (居中).step
model/fix_step/輔助夾臂.step
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

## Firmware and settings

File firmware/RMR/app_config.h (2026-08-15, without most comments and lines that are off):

#define APP_CONFIG_H_
#include "ti_msp_dl_config.h"
#include <stdint.h>
#include <stdbool.h>
#define POWER_SOURCE_DIRECT 1
#define POWER_SAVE_BUILD 0
#define DEBUG_BUILD 0
#define DEBUG_LP_BUILD 1
#if !DEBUG_BUILD && !DEBUG_LP_BUILD
#define FEATURE_PROD_SWD_DISABLE 1
#else
#define FEATURE_PROD_SWD_DISABLE 0
#endif
#define PROD_SWD_BOOT_WINDOW_MS     5000
#define BATT_SR516SW_SINGLE_R_MOHM  25000
#if DEBUG_BUILD
#define FW_VERSION_STR "V4.3.6_DBG"
#define CFG_DEFAULT_R_SERIES_MOHM   HW_SERIES_R_MOHM
#elif DEBUG_LP_BUILD
#define FW_VERSION_STR "V4.3.6_DBGL"
#define CFG_DEFAULT_R_SERIES_MOHM   HW_SERIES_R_MOHM
#elif POWER_SAVE_BUILD
#if POWER_SOURCE_DIRECT
#define FW_VERSION_STR "V4.3.6_ECO_D"
#define CFG_DEFAULT_R_SERIES_MOHM   HW_SERIES_R_MOHM
#else
#define FW_VERSION_STR "V4.3.6_ECO_B"
#define CFG_DEFAULT_R_SERIES_MOHM   (HW_SERIES_R_MOHM + 2 * BATT_SR516SW_SINGLE_R_MOHM)
#endif
#else
#if POWER_SOURCE_DIRECT
#define FW_VERSION_STR "V4.3.6_DIRECT"
#define CFG_DEFAULT_R_SERIES_MOHM   HW_SERIES_R_MOHM
#else
#define FW_VERSION_STR "V4.3.6_BATT"
#define CFG_DEFAULT_R_SERIES_MOHM   (HW_SERIES_R_MOHM + 2 * BATT_SR516SW_SINGLE_R_MOHM)
#endif
#endif
#define CFG_DEFAULT_R_BASE_MOHM     R_DYNAMIC_BASE_MOHM
#define DEV_FORCE_FACTORY_RESET         0
#define DEV_CLEAR_NVM_ON_POR            0
#define CFG_DEFAULT_ALS_EN              0
#define CFG_DEFAULT_LEVEL               4
#define CFG_DEFAULT_ALS_OFFSET          2
#define FEATURE_VOLTAGE_COMPENSATION    1
#define FEATURE_ADAPTIVE_GEAR_LIMIT     1
#define FEATURE_KEY_DEBOUNCE            1
#define FEATURE_ALS_MODE                1
#define FEATURE_ALS_OFFSET_ADJUST       1
#define FEATURE_ALS_SMOOTHING           1
#define FEATURE_INACTIVITY_AUTO_DIM_OFF 1
#define FEATURE_MEMORY_SAVE             1
#define FEATURE_SAVE_VERIFY             1
#define FEATURE_SAVE_RAM_SHADOW         1
#define FEATURE_LOWPOWER_STANDBY        1
#define FEATURE_LVP_FLASH_WARNING       1
#define FEATURE_FLASH_ANIMATION         1
#define FEATURE_RESTORE_NRST_IN_FLASH   1
#define FEATURE_AUTO_POWER_ON           1
#define FEATURE_SWD_IN_OFF_STATE        1
#define FLAG_VOLTAGE_COMPENSATION       (1 << 0)
#define FLAG_ADAPTIVE_GEAR_LIMIT        (1 << 1)
#define FLAG_ALS_MODE                   (1 << 2)
#define FLAG_INACTIVITY_AUTO_DIM        (1 << 3)
#define FLAG_LOWPOWER_STANDBY           (1 << 4)
#define FLAG_LVP_FLASH_WARNING          (1 << 5)
#define FLAG_SWD_IN_OFF_STATE           (1 << 6)
#define FLAG_AUTO_POWER_ON              (1 << 7)
#define FEATURE_RUNTIME_MASK ( \
    (FEATURE_VOLTAGE_COMPENSATION ? FLAG_VOLTAGE_COMPENSATION : 0) | \
    (FEATURE_ADAPTIVE_GEAR_LIMIT ? FLAG_ADAPTIVE_GEAR_LIMIT : 0) | \
    (FEATURE_ALS_MODE ? FLAG_ALS_MODE : 0) | \
    (FEATURE_INACTIVITY_AUTO_DIM_OFF ? FLAG_INACTIVITY_AUTO_DIM : 0) | \
    (FEATURE_LOWPOWER_STANDBY ? FLAG_LOWPOWER_STANDBY : 0) | \
    (FEATURE_LVP_FLASH_WARNING ? FLAG_LVP_FLASH_WARNING : 0) | \
    (FEATURE_SWD_IN_OFF_STATE ? FLAG_SWD_IN_OFF_STATE : 0) | \
    (FEATURE_AUTO_POWER_ON ? FLAG_AUTO_POWER_ON : 0))
#if DEBUG_BUILD
#define DEFAULT_FEATURE_FLAGS (FEATURE_RUNTIME_MASK | FLAG_SWD_IN_OFF_STATE)
#elif DEBUG_LP_BUILD
#define DEFAULT_FEATURE_FLAGS (FEATURE_RUNTIME_MASK & ~FLAG_SWD_IN_OFF_STATE)
#elif POWER_SAVE_BUILD
#define DEFAULT_FEATURE_FLAGS (FEATURE_RUNTIME_MASK & ~FLAG_SWD_IN_OFF_STATE)
#else
#define DEFAULT_FEATURE_FLAGS (FEATURE_RUNTIME_MASK & ~FLAG_SWD_IN_OFF_STATE)
#endif
#define PORT_I2C                SW_I2C_PORT
#define PIN_SW_SDA              SW_I2C_SW_SDA_PIN
#define PIN_SW_SCL              SW_I2C_SW_SCL_PIN
#define PORT_OUTPUT             OUTPUT_PINS_PORT
#define PIN_VCC_EN              OUTPUT_PINS_VCC_EN_PIN
#define PORT_BTN                BUTTONS_PORT
#define PIN_BT1                 BUTTONS_BT1_PIN
#define PIN_BT2                 BUTTONS_BT2_PIN
#define HW_PWM_INST             PWM_0_INST
#define HW_PWM_INDEX            DL_TIMER_CC_0_INDEX
#define HW_ADC_INST             ADC12_0_INST
#define MCU_CPU_FREQ_MHZ        24
#define CPU_CYCLES_PER_MS       (24000)
#define SYS_TICK_PERIOD_MS      1
#define EN_WWDT                 1
#define FLASH_SECTOR_A_ADDR     0x00003800
#define FLASH_SECTOR_B_ADDR     0x00003C00
#define FLASH_SECTOR_SIZE       1024
#define NVM_SLOT_SIZE           64
#define NVM_MAGIC               0xAA55AA5C
#define NVM_OFF_INTENT_MARK      0x5A
#define EN_AUTO_SAVE            1
#define FLASH_ERASE_TIME_MS     32
#define FLASH_PROG_TIME_MS      2
#define FLASH_RETRY_COUNT       3
#define FLASH_SLOT_ATTEMPTS     3
#define NVM_SAVE_MAX_RETRIES      5
#define TIME_NVM_AUTO_SAVE_DELAY_MS     30000
#define TIME_NVM_FORCE_SAVE_MS          600000
#define TIME_FLASH_MODE_TIMEOUT_MS      300000
#define PWM_REG_MAX             2399
#define BRT_SCALE_MAX           1000
#define MCU_VREF_MV             1400
#define HW_BATTERY_DIV_RATIO    3
#define VBATT_FULL_MV           (MCU_VREF_MV * HW_BATTERY_DIV_RATIO)
#define ADC_MAX_RESOLUTION      1023
#define ADC_GAIN_CAL            1000
#define ADC_TIMEOUT_MS          10
#define ADC_FILTER_SHIFT        3
#if POWER_SAVE_BUILD
#define TIME_ADC_READ_INTERVAL_MS   500
#else
#define TIME_ADC_READ_INTERVAL_MS   100
#endif
#define OPT3001_ADDR            0x44
#define OPT3001_REG_RESULT       0x00
#define OPT3001_REG_CONFIG       0x01
#define OPT3001_CFG_HI           0xC2
#define OPT3001_CFG_LO           0x10
#define OPT3001_MAX_LUX          8386500
#define R_DYNAMIC_BASE_MOHM     50
#define R_DYNAMIC_EXTRA_LOWV_MOHM 300000
#define R_DYNAMIC_EXTRA_CAP_MOHM  250000
#define R_DYNAMIC_DC_FACTOR_PCT   30
#define BRT_CACHE_DELTA_MV        30
#define BATT_STARTUP_HYSTERESIS_MV 100
#define R_DYNAMIC_FACTOR        50000000
#define R_DYNAMIC_OFFSET_MV     1900
#define BATT_MIN_WORK_V_MV      2000
#define BATT_LVP_EXTREME_MV     2100
#define BATT_POWER_LOSS_MV      2000
#define BATT_LVP_CRIT_MV        2300
#define POWERLOSS_COUNT         3
#define LVP_CRIT_COUNT          5
#define LVP_EXT_COUNT           5
#define EN_WALLS                1
#define WALL_MIN_V_BATT_MV      2400
#define BATT_MAX_DISCHARGE_UA   4000
#define BATT_MAX_DISCHARGE_UW   9000
#define LOW_BRT_GUARANTEE       30
#define V_DERATE_FULL_MV       3300
#define HW_LED_FORWARD_V_MV     2200
#define HW_LED_MAX_CURRENT_UA   2800
#define HW_SERIES_R_MOHM        360000
#define ALS_MAX_SLEW_RATE       20
#define ALS_SLEW_LOW             2
#define ALS_SLEW_MID             5
#define ALS_MIN_BRT             30
#define ALS_SQRT_FACTOR         5
#define ALS_CAP_BRT_LOW_LUX     600
#define ALS_CAP_BRT_HIGH_LUX    800
#if POWER_SAVE_BUILD
#define TIME_ALS_POLL_INTERVAL_MS   1000
#else
#define TIME_ALS_POLL_INTERVAL_MS   120
#endif
#define ALS_ERR_FAIL_COUNT      3
#define ALS_ERR_LOCKOUT_COUNT  3
#define TIME_ALS_ERR_RECOVER_MS     10000
#define ALS_ERR_BLINK_PERIOD_MS     1500
#define ALS_ERR_BLINK_ON_MS         600
#define CFG_MAX_LEVELS          9
#define SNAP_THRESHOLD_BRT      50
#define TIME_AUTO_DIM_S         2400
#define TIME_AUTO_SHUTDOWN_S    3000
#define DIM_LEVEL               5
#define LVP_FLASH_PERIOD_MS     2000
#define LVP_FLASH_ON_TIME_MS    50
#define LVP_FLASH_LEVEL_DIV     4
#define PWM_FLASH_LEVEL         50
#define PWM_FADE_INTERVAL_MS    12
#define PWM_FADE_STEP_DIV       10
#define KEY_DEBOUNCE_BITS       8
#define KEY_TIME_DEBOUNCE_MS    20
#define KEY_TIME_SHORT_0_8S_MS  800
#define KEY_TIME_SHORT_MAX_MS   1500
#define KEY_TIME_LONG_PRESS_MS  1500
#define KEY_TIME_FACTORY_RESET_MS 5000
#define TIME_SEC_MS               1000
#define STARTUP_FAIL_BLINK_DELAY_MS 100
#define LED_BLINK_BRT             300
#define TEST_MAGIC                0x54455354
#pragma pack(push, 1)
typedef struct {
    uint32_t magic;
    uint32_t seq_id;
    uint32_t params;
    uint32_t features;
    uint32_t r_base;
    uint32_t r_series;
    uint32_t v_led_fw;
    uint32_t i_max_ua;
    uint32_t batt_p_uw;
    uint32_t als_min_brt;
    uint32_t lvp_crit;
    uint32_t lvp_ext;
    uint8_t  default_level;
    uint8_t  als_sqrt_factor;
    uint8_t  als_cap_low_x100;
    uint8_t  als_cap_high_x100;
    uint8_t  reserved[8];
    uint32_t crc32;
} __attribute__((aligned(8))) NVM_Data_t;
#pragma pack(pop)
typedef enum { SYS_OFF = 0, SYS_RUN, SYS_LVP_CRIT, SYS_FLASH_MODE, SYS_TEST_MODE, SYS_ALS_ERR } SysState_t;
extern volatile uint32_t g_tick_ms;
extern volatile uint32_t g_rst_cause;
extern SysState_t sys_state;
extern NVM_Data_t sys_memory;
extern volatile uint32_t g_vbatt_mv_raw;
extern volatile uint32_t g_vbatt_mv_filtered;
extern volatile uint32_t g_inactivity_sec;
extern volatile bool g_is_dimmed;
extern volatile bool g_is_overshot;
extern const uint16_t CFG_BRT_MAP[CFG_MAX_LEVELS];
extern const int16_t AUTO_OFFSET_PCT[5];

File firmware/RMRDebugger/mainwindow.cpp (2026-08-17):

#include "MainWindow.h"
#include "datamatrix.h"
#include <QApplication>
#include <QCoreApplication>
#include <windows.h>
    int prmMax[] = {9999, 999999, 5000, 100000, 99999999, 1000, 5000, 5000, 8, 20, 20, 20};
#include <QVBoxLayout>
#include <QHBoxLayout>
#include <QGridLayout>
#include <QHeaderView>
#include <QMessageBox>
#include <QDateTime>
#include <QPixmap>
#include <QFileDialog>
#include <QInputDialog>
#include <QSqlQuery>
#include <QFile>
#include <QTextStream>
#include <QRegularExpression>
#include <QFrame>
#include <QScrollArea>
#include <QFrame>
#include <QGraphicsLayout>
#include <QLegendMarker>
#include <QSplitter>
#include <vector>
#include <QTimer>
#include <QIcon>
#include <QSet>
#include <QSettings>
#include <QSerialPortInfo>
#include <QTcpServer>
#include <QTcpSocket>
#include <QJsonObject>
#include <QJsonDocument>
#include <QJsonArray>

#pragma pack(push, 8)
struct JLINKARM_EMU_CONNECT_INFO {
    uint32_t SerialNo;
    uint8_t  Connection;
    uint8_t  aIPAddr[16];
    uint8_t  aPad[3];
    int      TimeSize;
    int      TimeCnt;
    uint16_t Status;
    uint8_t  aMACAddr[6];
    char     aHostStr[32];
};
#pragma pack(pop)

typedef int (*JLINK_EMU_GetListFunc)(int, void*, int);
typedef void (*JLinkLogCB)(const char*);
typedef void (*JLINK_SetLogFunc)(JLinkLogCB);

static QLibrary* g_globalScannerLib = nullptr;
static MainWindow* g_mainWindowContext = nullptr;

void GlobalJLinkLogHandler(const char* s) {
    if (g_mainWindowContext && s) {
        QString logStr = QString::fromUtf8(s).trimmed();
        if (!logStr.isEmpty()) {
            QMetaObject::invokeMethod(g_mainWindowContext, "onRawJLinkLog", Qt::QueuedConnection, Q_ARG(QString, logStr));
        }
    }
}

MainWindow::MainWindow(QWidget *parent) : QMainWindow(parent) {
    g_mainWindowContext = this;
    plotClock.start();
    setWindowTitle("RMR Factory Programmer");
    setWindowIcon(QIcon(":/logo.ico"));
    setMinimumSize(1180, 780);
    resize(1450, 950);

    initDatabase();
    setupUI();
    /* Power-Z KM003C: 真实电压电流计, HID Basic Mode, 200ms 轮询 */
    pzWorker = new PowerZWorker(this);
    connect(pzWorker, &PowerZWorker::telemetry, this, &MainWindow::onPowerZTelemetry);
    connect(pzWorker, &PowerZWorker::stateChanged, this, [this](bool ok, const QString &detail){
        if (!lblPzStatus) return;
        lblPzStatus->setText(ok ? "Power-Z: 已连接" : detail);
        lblPzStatus->setStyleSheet(ok ? "border: none; color: #198754; font-size: 8pt; font-weight: bold;"
                                      : "border: none; color: #C00000; font-size: 8pt; font-weight: bold;");
    });
    pzWorker->start(200);
    applyTheme();
    setupIpc();

    autoScanTimer = new QTimer(this);
    connect(autoScanTimer, &QTimer::timeout, this, [this](){ scanProbes(false); });
    autoScanTimer->start(2000);

    QTimer::singleShot(500, this, [this](){ scanProbes(false); });
    /* ????????: ?? QtCharts ??? append/remove + setRange ???????? */
    chartRefreshTimer = new QTimer(this);
    connect(chartRefreshTimer, &QTimer::timeout, this, [this](){
        if (viewVBatt) viewVBatt->viewport()->update();
        if (viewLux) viewLux->viewport()->update();
        if (viewPwmBrt) viewPwmBrt->viewport()->update();
    });
    chartRefreshTimer->start(200);
    /* 窗口显示并完成首次布局后再恢复分栏比例, 避免被初始布局覆盖 */
    QTimer::singleShot(0, this, &MainWindow::restoreLayoutState);
}

MainWindow::~MainWindow() {
    g_mainWindowContext = nullptr;
    for (auto w : activeWorkers) {
        w->disconnect(this);
        w->stop();
        w->wait(1000);
        w->deleteLater();
    }
    if (pzWorker) pzWorker->stop();
    if (consoleWindow) consoleWindow->deleteLater();
    db.close();
}

void MainWindow::resizeEvent(QResizeEvent *event) {
    QMainWindow::resizeEvent(event);
    /* 固定字号与内边距：不再随窗口缩放，避免元素被压缩 (设计基准 1450x950) */
    applyPendingRatios();
}

void MainWindow::saveLayoutState() {
    QSettings s("RMR", "RMRDebugger");
    s.setValue("window/geometry", saveGeometry());
    /* 保存各分栏的归一化比例, 不依赖页签可见性/绝对像素 */
    auto saveSplit = [&](const char* key, QSplitter* sp){
        if (!sp) return;
        QVariantList vl;
        if (pendingRatios.contains(sp)) {
            for (double r : pendingRatios.value(sp)) vl.append(r);
        } else {
            QList<int> sz = sp->sizes();
            int total = 0;
            for (int v : sz) total += v;
            if (total <= 0) return;
            for (int v : sz) vl.append(qreal(v) / qreal(total));
        }
        s.setValue(key, vl);
    };
    saveSplit("layout/global", globalSplitter);
    saveSplit("layout/right", rightSplitter);
    saveSplit("layout/test", testSplitter);
    saveSplit("layout/cols", colsSplitter);
}

void MainWindow::applyPendingRatios() {
    for (auto it = pendingRatios.begin(); it != pendingRatios.end(); ) {
        QSplitter* sp = it.key();
        const QList<double>& ratios = it.value();
        if (sp && sp->isVisible() && sp->width() > 0) {
            int total = (sp->orientation() == Qt::Horizontal) ? sp->width() : sp->height();
            if (total > 0) {
                QList<int> sizes;
                for (double r : ratios) sizes.append(qRound(r * total));
                sp->setSizes(sizes);
                it = pendingRatios.erase(it);
                continue;
            }
        }
        ++it;
    }
}

void MainWindow::restoreLayoutState() {
    QSettings s("RMR", "RMRDebugger");
    QByteArray geo = s.value("window/geometry").toByteArray();
    if (!geo.isEmpty()) restoreGeometry(geo);
    pendingRatios.clear();
    auto restoreSplit = [&](const char* key, QSplitter* sp) {
        if (!sp) return;
        QVariantList vl = s.value(key).toList();
        if (vl.size() != sp->count() || vl.isEmpty()) return;
        QList<double> ratios;
        for (auto v : vl) ratios.append(v.toDouble());
        pendingRatios[sp] = ratios;
    };
    restoreSplit("layout/global", globalSplitter);
    restoreSplit("layout/right", rightSplitter);
    restoreSplit("layout/test", testSplitter);
    restoreSplit("layout/cols", colsSplitter);
    applyPendingRatios();
}

void MainWindow::closeEvent(QCloseEvent *event) {
    saveLayoutState();
    QMainWindow::closeEvent(event);
}

void MainWindow::applyTheme() {
    /* 固定字号/内边距 (设计基准 1450x950), 不随窗口缩放 */
    QString qss = QString(
                      "QWidget { font-family: 'Segoe UI', Arial; font-size: %1pt; color: #333333; } "
                      "QMainWindow { background-color: #F4F6F9; } "
                      "QDialog, QMessageBox { background-color: #FFFFFF; } "
                      "QMessageBox QLabel { color: #333333; font-size: %2pt; font-weight: bold; } "
                      "QPushButton { background-color: #0078D7; color: white; border-radius: 3px; padding: %3px 12px; font-weight: bold; border: none; } "
                      "QPushButton:hover { background-color: #005A9E; } "
                      "QPushButton#BtnGreen { background-color: #198754; } "
                      "QPushButton#BtnGreen:hover { background-color: #157347; } "
                      "QPushButton#BtnRed { background-color: #DC3545; } "
                      "QPushButton#BtnRed:hover { background-color: #C82333; } "
                      "QPushButton#BtnPurple { background-color: #6F42C1; color: white; font-size: %2pt; padding: %3px; } "
                      "QPushButton#BtnPurple:hover { background-color: #59339D; } "
                      "QGroupBox { border: 1px solid #B0C4DE; border-radius: 4px; margin-top: 10px; font-weight: bold; color: #004085; padding-top: 15px; background-color: #FFFFFF; font-size: %2pt;} "
                      "QGroupBox::title { subcontrol-origin: margin; left: 10px; padding: 0 5px; color: #004085; } "
                      "QLineEdit, QSpinBox, QComboBox { border: 1px solid #CCCCCC; padding: 3px; border-radius: 3px; background: #FFFFFF; font-size: %1pt; } "
                      "QLineEdit[readOnly=\"true\"] { background: #E9ECEF; color: #495057; font-weight: bold; } "
                      "QTextEdit { border: 1px solid #B0C4DE; border-radius: 4px; background: #FFFFFF; color: #333333; font-family: Consolas; font-size: %1pt; } "
                      "QProgressBar { border: 1px solid #CCCCCC; text-align: center; color: black; border-radius: 3px; font-weight: bold; background-color: #E9ECEF; height: 18px; } "
                      "QProgressBar::chunk { background-color: #28A745; border-radius: 2px; } "
                      "QTabWidget::pane { border: 1px solid #B0C4DE; background: #FFFFFF; border-radius: 4px; } "
                      "QTabBar::tab { background: #E9ECEF; color: #495057; padding: 6px 20px; border: 1px solid #B0C4DE; border-bottom: none; border-top-left-radius: 4px; border-top-right-radius: 4px; margin-right: 2px; font-weight: bold; font-size: %2pt; } "
                      "QTabBar::tab:selected { background: #FFFFFF; color: #0078D7; border-top: 3px solid #0078D7; } "
                      "QTableWidget { background-color: #FFFFFF; alternate-background-color: #F8F9FA; color: #333333; gridline-color: #E0E0E0; border: 1px solid #B0C4DE; } "
                      "QHeaderView::section { background-color: #F1F3F5; padding: 4px; border: 1px solid #DEE2E6; font-weight: bold; color: #495057; } "
                      "QSplitter::handle:vertical { background-color: #DEE2E6; border: 1px solid #CCCCCC; border-radius: 2px; margin: 2px 0px; height: 6px; } "
                      "QSplitter::handle:vertical:hover { background-color: #0078D7; } "
                      "QScrollArea { background-color: #F4F6F9; border: none; } "
                      "QScrollBar:vertical { background: #F1F3F5; width: 12px; margin: 0; } "
                      "QScrollBar::handle:vertical { background: #C5CED6; border-radius: 6px; min-height: 30px; margin: 2px; } "
                      "QScrollBar::handle:vertical:hover { background: #9FB2C8; } "
                      "QScrollBar::add-line:vertical, QScrollBar::sub-line:vertical { height: 0; } "
                      "QScrollBar:horizontal { background: #F1F3F5; height: 12px; margin: 0; } "
                      "QScrollBar::handle:horizontal { background: #C5CED6; border-radius: 6px; min-width: 30px; margin: 2px; } "
                      "QScrollBar::handle:horizontal:hover { background: #9FB2C8; } "
                      "QScrollBar::add-line:horizontal, QScrollBar::sub-line:horizontal { width: 0; } "
                      ).arg(8).arg(9).arg(6);
    this->setStyleSheet(qss);
}

void MainWindow::setFwPath(const QString& path) {
    txtFwPath->setText(path);
    updateFirmwareInfo(path);
    for (auto w : activeWorkers) w->fwPath = path;
}

void MainWindow::setupIpc() {
    /* 本地隐藏调试接口: 127.0.0.1:17345, JSON 行协议 (供自动化测试/外部读取实时数据) */
    ipcServer = new QTcpServer(this);
    if (!ipcServer->listen(QHostAddress::LocalHost, 17345)) {
        onLog(0, QString("[SYS] IPC 接口启动失败: %1").arg(ipcServer->errorString()));
        return;
    }
    onLog(0, "[SYS] IPC 接口已启动: 127.0.0.1:17345 (JSON)");
    connect(ipcServer, &QTcpServer::newConnection, this, [this](){
        while (QTcpSocket *s = ipcServer->nextPendingConnection()) {
            ipcClients.append(s);
            ipcBuffers.insert(s, QByteArray());
            connect(s, &QTcpSocket::readyRead, this, [this, s](){ handleIpcRead(s); });
            connect(s, &QTcpSocket::disconnected, this, [this, s](){
                ipcClients.removeAll(s); ipcBuffers.remove(s); s->deleteLater();
            });
            ipcSendHello(s);
        }
    });
}

void MainWindow::ipcSend(QTcpSocket *s, const QJsonObject& obj) {
    if (!s) return;
    QByteArray line = QJsonDocument(obj).toJson(QJsonDocument::Compact) + '\n';
    s->write(line);
    s->flush();
}

void MainWindow::ipcBroadcast(const QJsonObject& obj) {
    if (ipcClients.isEmpty()) return;
    QByteArray line = QJsonDocument(obj).toJson(QJsonDocument::Compact) + '\n';
    for (QTcpSocket *s : ipcClients) { s->write(line); s->flush(); }
}

void MainWindow::ipcSendHello(QTcpSocket *s) {
    QJsonObject hello;
    hello["type"] = "hello";
    hello["app"] = "RMRDebugger";
    hello["ts"] = QString::number(QDateTime::currentMSecsSinceEpoch());
    hello["fw_path"] = txtFwPath ? txtFwPath->text() : QString();
    hello["active_probe"] = QString::number(cmbActiveProbe ? cmbActiveProbe->currentData().toUInt() : 0);
    hello["poll_enabled"] = chkPoll && chkPoll->isChecked();
    hello["poll_interval_ms"] = spinPollMs ? spinPollMs->value() : 150;
    QJsonArray probes;
    for (auto it = activeWorkers.constBegin(); it != activeWorkers.constEnd(); ++it) {
        QJsonObject p;
        p["sn"] = QString::number(it.key());
        p["type"] = it.value()->probeType == ProbeType::XDS110 ? "XDS110" : "JLINK";
        p["connected"] = lastStatusCode.value(it.key(), 0) == 1;
        p["status"] = lastStatusMsg.value(it.key(), QString());
        p["uuid"] = lastUuid.value(it.key(), QString());
        p["fw"] = lastFwVer.value(it.key(), QString());
        if (lastTelemetry.contains(it.key()))
            p["telemetry"] = QJsonObject::fromVariantMap(lastTelemetry[it.key()]);
        probes.append(p);
    }
    hello["probes"] = probes;
    if (pzWorker) {
        QJsonObject pz;
        pz["connected"] = pzWorker->isConnected();
        pz["vbus_v"] = pzWorker->vbus();
        pz["ibus_a"] = pzWorker->ibus();
        pz["power_w"] = pzWorker->power();
        pz["temp_c"] = pzWorker->tempC();
        pz["avg_v"] = pzWorker->avgV();
        pz["avg_a"] = pzWorker->avgI();
        pz["avg_w"] = pzWorker->avgP();
        pz["stat_sec"] = pzWorker->statSec();
        hello["powerz"] = pz;
    }
    ipcSend(s, hello);
}

void MainWindow::handleIpcRead(QTcpSocket *s) {
    ipcBuffers[s] += s->readAll();
    while (true) {
        int nl = ipcBuffers[s].indexOf('\n');
        if (nl < 0) break;
        QByteArray line = ipcBuffers[s].left(nl).trimmed();
        ipcBuffers[s].remove(0, nl + 1);
        if (line.isEmpty()) continue;
        QJsonParseError err;
        QJsonDocument doc = QJsonDocument::fromJson(line, &err);
        if (err.error != QJsonParseError::NoError || !doc.isObject()) {
            QJsonObject r; r["type"]="error"; r["msg"]="bad json"; ipcSend(s, r);
            continue;
        }
        handleIpcCommand(s, doc.object());
    }
}

void MainWindow::handleIpcCommand(QTcpSocket *s, const QJsonObject& cmd) {
    QString c = cmd["cmd"].toString();
    auto reply = [&](bool ok, const QString& msg = QString()){
        QJsonObject r; r["type"]="reply"; r["cmd"]=c; r["ok"]=ok; r["msg"]=msg; ipcSend(s, r);
    };
    auto toU32 = [](const QJsonValue& v, uint32_t def) -> uint32_t {
        if (v.isString()) return v.toString().toUInt(nullptr, 0);
        if (v.isDouble()) return (uint32_t)v.toInt();
        return def;
    };
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

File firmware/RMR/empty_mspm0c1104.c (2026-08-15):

#include "app_config.h"
#include "hal_keys.h"
#include "hal_opt3001.h"
#include "sys_battery.h"
#include "sys_led_pwm.h"
#include "sys_mode.h"
#include "nvm_flash.h"
#include "test_mailbox.h"

#if defined(__clang__) || defined(__GNUC__) || defined(__TI_COMPILER_VERSION__)
__attribute__((used, section(".fw_version")))
const char g_fw_version_flash[16] = FW_VERSION_STR;
#else
#pragma DATA_SECTION(g_fw_version_flash, ".fw_version")
#pragma RETAIN(g_fw_version_flash)
const char g_fw_version_flash[16] = FW_VERSION_STR;
#endif

#define POR_MAGIC 0x5AA5C33C

#if defined(__clang__) || defined(__GNUC__) || defined(__TI_COMPILER_VERSION__)
uint32_t g_por_magic __attribute__((section(".TI.noinit")));
bool g_flash_mode_used __attribute__((section(".TI.noinit")));
bool g_off_intent __attribute__((section(".TI.noinit")));
#elif defined(__GNUC__)
uint32_t g_por_magic __attribute__((section(".noinit")));
bool g_flash_mode_used __attribute__((section(".noinit")));
bool g_off_intent __attribute__((section(".noinit")));
#else
uint32_t g_por_magic __attribute__((section(".noinit")));
bool g_flash_mode_used __attribute__((section(".noinit")));
bool g_off_intent __attribute__((section(".noinit")));
#endif

#if FEATURE_PROD_SWD_DISABLE
static bool prod_swd_disabled = false;   /* 本电源会话是否已禁用 SWD/NRST(热复位后重新走 boot 窗口) */
static void prod_disable_swd_nrst(void) {
    if (prod_swd_disabled) return;
    prod_swd_disabled = true;
    DL_SYSCTL_disableSWD();       /* 禁用后仅 POR 可恢复: 量产正常态 SWD 不可连 */
    DL_SYSCTL_disableNRSTPin();   /* NRST 复位功能一并禁用(该引脚未使用) */
}
#endif
static uint32_t flash_mode_tick = 0;
/* 进入 FLASH_MODE(唯一量产调试通道): 测压达标才进; 量产版仅 boot 窗口内有效(窗口外 SWD 已禁用) */
static void try_enter_flash_mode(void) {
#if FEATURE_PROD_SWD_DISABLE
    if (g_tick_ms >= PROD_SWD_BOOT_WINDOW_MS) return;   /* 窗口外进 FLASH_MODE 无意义(SWD 已禁) */
#endif
    if (g_vbatt_mv_filtered >= sys_memory.lvp_ext) {   /* 测压达标才进入 Flash 模式 */
        g_flash_mode_used = true;
        flash_mode_tick = g_tick_ms;   /* 起始 tick(差值比较防回绕) */
        sys_state = SYS_FLASH_MODE;
        led_blink_twice();
#if FEATURE_RESTORE_NRST_IN_FLASH
        DL_GPIO_setPins(PORT_OUTPUT, PIN_VCC_EN);
        delay_cycles(CPU_CYCLES_PER_MS);
#endif
    } else {
        g_test_box.boot_refuse_reason = BOOT_REFUSE_VOLT;
    }
}

volatile uint32_t g_tick_ms = 0;
volatile uint32_t g_rst_cause = 0;   /* SYSCTL RSTCAUSE ID, captured once at boot (read-to-clear) */

/* 1ms ????: MSPM0C1103/1104 ??? SysTick(TI E2E ??, ???????? 0),
   ????? GPTIMER14 ?????????????????? >1ms(????),
   ?????????????"??"??(?? 5s ????/1.5s ??/LVP/ALS ???)???? */
static void tick_timer_init(void) {
    const DL_TimerG_ClockConfig tickClockConfig = {
        .clockSel = DL_TIMER_CLOCK_BUSCLK,
        .divideRatio = DL_TIMER_CLOCK_DIVIDE_1,
        .prescale = 0U
    };
    const DL_TimerG_TimerConfig tickTimerConfig = {
        .timerMode = DL_TIMER_TIMER_MODE_PERIODIC_UP,
        .period = CPUCLK_FREQ / 1000u - 1u,   /* 24MHz BUSCLK -> 1ms */
        .startTimer = DL_TIMER_STOP,
        .genIntermInt = DL_TIMER_INTERM_INT_DISABLED,
        .counterVal = 0U
    };
    DL_TimerG_enablePower(TIMG14);
    delay_cycles(POWER_STARTUP_DELAY);
    DL_TimerG_setClockConfig(TIMG14, (DL_TimerG_ClockConfig *) &tickClockConfig);
    DL_TimerG_initTimerMode(TIMG14, (DL_TimerG_TimerConfig *) &tickTimerConfig);
    DL_TimerG_enableInterrupt(TIMG14, DL_TIMER_INTERRUPT_ZERO_EVENT);
    NVIC_EnableIRQ(TIMG14_INT_IRQn);
    DL_TimerG_startCounter(TIMG14);
}

/* MSPM0C110x 的 SYSOSC 实际只能运行在 24MHz: SYSOSCCFG.FREQ=1(4M) 写入后寄存器
   生效但硅片仍以 24MHz 跑, 若再把 TIMG14 LOAD 设成 4000, g_tick_ms 会变成
   167us/tick, 全部按键/ALS/LVP 计时被压缩约 6 倍(1.5s 一按就亮、5s 切换也不满).
   修复: 恒定 24MHz, LOAD 恒为 CPUCLK_FREQ/1000-1, g_tick_ms 恒为真 1ms;
   OFF 态短暂运行不降频(STANDBY1 深睡停机才是 uA 级功耗来源). */
static void sysclk_set_freq(bool high) {
    (void)high;   /* 全版本恒定 24MHz: 保留调用点, 但不再切 4M */
    DL_TimerG_stopCounter(TIMG14);
    DL_TimerG_setLoadValue(TIMG14, CPUCLK_FREQ / 1000u - 1u);
    delay_cycles(1000);   /* 稳定后重启 */
    DL_TimerG_startCounter(TIMG14);
}

void TIMG14_IRQHandler(void) {
    DL_TimerG_clearInterruptStatus(TIMG14, DL_TIMER_INTERRUPT_ZERO_EVENT);
    g_tick_ms++;
}
volatile uint32_t g_inactivity_sec = 0;
volatile bool g_is_dimmed = false;

SysState_t sys_state = SYS_OFF;
NVM_Data_t sys_memory;

volatile char g_debug_str[64] = "Initializing..."; 
static uint32_t str_idx = 0;

void GPIOA_IRQHandler(void) {
    DL_GPIO_clearInterruptStatus(PORT_BTN, PIN_BT1 | PIN_BT2);
}

#if !POWER_SAVE_BUILD
static void append_str(const char* s) { while (*s && str_idx < 63) { g_debug_str[str_idx++] = *s++; } }
static void append_int(uint32_t val, uint8_t min_digits) {
    char temp[12]; int i = 0;
    if (val == 0) { temp[i++] = '0'; } 
    else { while (val > 0) { temp[i++] = (val % 10) + '0'; val /= 10; } }
    while (i < min_digits) { temp[i++] = '0'; }
    while (i > 0 && str_idx < 63) { g_debug_str[str_idx++] = temp[--i]; }
}
static void update_debug_string(void) {
    str_idx = 0;
    if (sys_state == SYS_OFF) append_str("[OFF] ");
    else if (sys_state == SYS_RUN) append_str(g_is_als_mode ? "[ALS] " : "[MAN] ");
    else if (sys_state == SYS_TEST_MODE) append_str("[TST] ");
    else if (sys_state == SYS_FLASH_MODE) append_str("[FLS] ");
    else if (sys_state == SYS_ALS_ERR) append_str("[ERR] ");
    else append_str("[LVP] ");
    
    append_str("Lvl:"); append_int(sys_memory.params & 0xFF, 1);
    append_str(" Ofs:"); append_int((sys_memory.params >> 16) & 0xFF, 1);
    append_str(" V:"); append_int(g_vbatt_mv_filtered, 4);
    append_str("mV Max:"); append_int(battery_get_safe_brt(BRT_SCALE_MAX), 1);
    append_str(" P:"); append_int(g_last_applied_pwm, 4);
    append_str(" Rst:"); append_int(g_rst_cause, 2);

    while (str_idx < 63) { g_debug_str[str_idx++] = ' '; } g_debug_str[63] = '\0';
}
#endif

/* NVM off-intent sentinel (NVM_Data_t.reserved[0]): 0x5A = intentionally off.
   Persisted so that any reset while OFF (WWDT/BOR/debugger) boots back to OFF
   instead of honoring AUTO_POWER_ON; only an explicit user power-on clears it. */
static bool nvm_off_intent_get(void) { return sys_memory.reserved[0] == NVM_OFF_INTENT_MARK; }
static void nvm_off_intent_set(bool off) {
    uint8_t v = off ? NVM_OFF_INTENT_MARK : 0x00;
    if (sys_memory.reserved[0] != v) {
        sys_memory.reserved[0] = v;
        nvm_mark_dirty();
        nvm_save_dirty();
    }
}
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

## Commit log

2026-08-09 固件 V4.3.1 + RMRDebugger: 修复 XDS110 连接/init 判定/IPC bool 解析, 固件 mailbox cfg 镜像同步, 清理构建产物, 补全 README
    [app_config.h, debugworkers.cpp, empty_mspm0c1104.c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]
2026-08-10 固件 mailbox 新增原始电压 vbatt_raw_mv(0xB0); 调试器 SEND_SYS_CMD 写配置防清 NVM + 保留 ALS/offset 高位; GUI 遥测改固定长条/图表限点防卡死/电压显示原始值
2026-08-10 调试器: 布局可拖动分栏+比例记忆/ALS映射预览/IPC tab-autotest-calib增强; AUTO-TEST修PWM判定与亮光注入; 固件cmd6 TEST->RUN补mode_init
2026-08-10 清理误提交的测试文件
2026-08-10 固件: LED 亮度映射修复 - HW_LED_MAX_CURRENT_UA 默认 30000->2800uA(实测峰值2744uA), brt 0-1000 线性映射不再饱和; 重新生成 RMR.hex
    [app_config.h]
2026-08-10 固件: 新增硬件功率(0xB4, 当前PWM反推x原始电压) + ALS最低亮度30; 调试器: 三图一行(Y轴自适应/X轴自动滚动), 软件按键+/-/同时按下自动拦截物理按键松开解除, IPC key支持both/block
2026-08-10 调试器: 图表改固定10s时间窗口(X轴单调时钟, 只显示最近10s, 窗口外数据裁剪), Y轴自适应保持
2026-08-10 调试器: 硬件功率显示组合格式 - X.XXX mW (功率冗余%): 当前PWM反推, pwm=1199->50%
2026-08-10 固件: brt 0-1000全量程线性(峰值电流限幅) + LVP_CRIT回升迟滞自动恢复; 调试器: PWM/2399原始值显示, 图表10s窗口裁剪+Y轴最小跨度+强制重绘, OpenOCD端口避让
2026-08-10 固件: 进入测试态保持当前亮度(ovr_brt_val默认取g_current_brt), 修复unlock瞬间LED灭灯闪烁; 同步syscfg生成文件与最新hex
2026-08-10 调试器: 修复虚拟按键行丢失(补回vOvr->addLayout(lKey)), 拆两行布局, &转义显示[+&-], 监视器新增Params实时格; 固件: 测试邮箱cfg_params每tick同步
    [mainwindow.cpp]
2026-08-10 虚拟按键真实按压语义+状态操作合并显示+看门狗; 固件TEST态LED按键真实模式; State格显示ALS/手动; 连接清残留覆盖
2026-08-10 固件V4.3.1增量6: 电压降额+PWM补偿根因修复(恒流模型 duty=i_req/i_peak, V_DERATE_FULL_MV 3300 线性降额, 删BRT缓存); CCS21 post-build 改 tiarmobjcopy 生成HEX 根治 tiarmhex 版本段bug; README 更新
    [app_config.h, sys_battery.c]
2026-08-10 固件V4.3.1增量7: 1ms硬件时基改GPTIMER14(MSPM0C1104无硬件SysTick, TI E2E确认寄存器写无效) TIMG14周期中断驱动g_tick_ms, 修复5s模式切换/1.5s关机/LVP/ALS恢复等全部毫秒计时; README更新
    [empty_mspm0c1104.c]
2026-08-10 调试器: 接入Power-Z KM003C真实电压电流计(HID Basic Mode 200ms轮询), 监视条6位小数显示真实V/A/功耗W/平均V/A/温度, IPC新增powerz帧与hello.powerz字段, 拔插自动重连; README更新
2026-08-10 固件V4.3.1双版本: POWER_SOURCE_DIRECT编译宏区分 直连版(V4.3.1_DIRECT, 稳压电源1.6-3.6V+120-635Ω限流, 不算电池内阻) / 电池版(V4.3.1_BATT, 2xSR516SW 3.1V, r_series=360Ω+2x25Ω内阻典型值可NVM校准); hex归档firmware/RMR/hex; README更新
2026-08-10 固件V4.3.2+调试器: 虚拟按键与真实按键一致(授权后任意状态注入生效, TEST态保持当前模式ALS/MAN, +/-调档调偏移, 双键5s切换); 调试器连接失败自动清理残留openocd进程(限频5s taskkill后自动重连); IPC key命令与UI一致自动解锁; README更新
2026-08-11 固件V4.3.3: FLASH模式双键长按1.5s可正常开机(与OFF态一致先测压达标才启动, 不达标闪灯100ms, 5min超时复位保留); 调试器telemetry新增cfg_features(mailbox 0x78)修复误判features被清零; hex与rmrdebuger.exe更新; README记录SWD真机验证(state 0->3->1)
    [app_config.h, debugworkers.cpp, empty_mspm0c1104.c]
2026-08-11 固件V4.3.3省电版ECO: 新增POWER_SAVE_BUILD编译宏(默认0, 与POWER_SOURCE_DIRECT正交); 省电措施=主循环WFI睡眠替代24MHz忙等/调试箱每tick刷新关闭/ADC+VREF采样间隙断电(500ms轮询)/OPT3001手动与OFF态shutdown(ALS轮询1s)/PWM亮度不变不重算/出厂默认清SWD位OFF态进STANDBY0深睡; 产物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
2026-08-11 固件V4.3.3优化: ECO动态降频(关机/FLASH态SYSOSC切4MHz省电, 运行态回24MHz, GPTIMER14同步重配tick恒1ms); 按键调档改30s后台延迟保存省NVM磨损(关机/LVP/掉电仍强制); ALS连续3次故障自恢复后锁定拒绝切回防闪烁死循环; ECO启动先断ADC/VREF电源域+VREF内部基准采样间隙门控; FLASH超时改差值比较防回绕; 四变体0错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
2026-08-11 固件V4.3.3调试版DEBUG_BUILD: 新增编译宏(默认0, 与DIRECT/ECO正交), 调试版=测试板直供+全程SWD保活(OFF态跳过STANDBY0深睡/掉电不执行SHUTDOWN仅存脏配置/出厂默认置位SWD位), ECO降频/NVM等特性全部保留; 产物RMR_DBG.hex(V4.3.3_DBG), 已烧录测试板验证OFF态SWD保持+telemetry实时; READM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
2026-08-11 固件V4.3.3低功耗调试版DEBUG_LP_BUILD: 新增编译宏(默认0), OFF态强制深睡(WFI+STANDBY0, 忽略NVM SWD位, SWD自然断开)+主循环WFI+关ALS, 开机/运行态SWD保持, 掉电不SHUTDOWN仅存脏配置; 产物RMR_DBGL.hex(V4.3.3_DBGL), 已烧录测试板验证: RUN态SWD+telemetry实时, OFF态STAND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
2026-08-11 RMRDebugger: Power-Z 10s滑动窗口平均统计(Avg V/I/P + 窗口时长 + Reset按钮), PowerZWorker改用窗口队列(200ms采样约50样本, 弹出超窗样本), IPC hello/powerz事件新增avg_v/avg_a/avg_w/stat_sec, 新增powerz reset命令; KM003C实测avg_v 3.2009V稳定/窗口满10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
    [mainwindow.cpp]
2026-08-11 fix(fw): STANDBY0 deep-sleep wakeup reliability
    - WWDT kept counting in STANDBY0 (LFCLK) and reset the device every 500ms;
    stretch period to ~8192s before deep sleep, restore 500ms after wakeup
    - Add IOMUX IO wakeup (WUEN/WCOMP) for BT1/BT2 as primary STANDBY0 wake
    source, keep GPIO edge IRQ as backup
    - Clear GPIOA/TIMG14 pending + controlled WFI (__disable_irq) to prevent
    1ms tick from aborting standby entry
    - Verified: DEBUG_LP_BUILD / DEBUG_BUILD / default all 0 errors 0 warnings;
    RMR_DBGL.hex (V4.3.3_DBGL) regenerated
    [empty_mspm0c1104.c]
2026-08-11 feat(fw): dual-key hold UX - 1.5s immediate off, 5s blink+ALS on, release before 5s stays off
    - hal_keys.c: EVT_BOTH_LONG_1_5S now fires while held in any state so RUN
    mode turns the LED off immediately at 1.5s (was: only on release)
    - main loop OFF state: new EVT_BOTH_LONG_5S branch - blink twice then power
    on in ALS mode (with startup voltage check, ALS flag saved to NVM)
    - Release between 1.5s and 5s keeps device OFF (no event generated)
    - Unchanged: OFF 1.5s power-on, RUN 5s mode toggle, FLASH 0.8s entry
    - Verified: DBGL/DBG/default builds 0 errors 0 warnings; RMR_DBGL.hex updated
    [empty_mspm0c1104.c, hal_keys.c]
2026-08-11 fix(fw): keep SYS_OFF when debugger auth is active
    test_mailbox_task forced sys_state to SYS_TEST_MODE every tick while the
    debugger authorization (magic+host_version) was set, so a physical dual-key
    1.5s power-off was instantly overridden and the LED turned back on.
    - Skip forced TEST entry and test-mode-exit->FLASH transition while OFF
    - Verified on target via IPC: with auth re-applied, state stays SYS_OFF (0x00)
    after power off; deep sleep (STANDBY0) re-engages (SWD drops, fw reads V0.0)
    - DBGL build 0 errors 0 warnings; RMR_DBGL.hex flashed & verified
2026-08-11 fix(fw): deep-sleep release-reboot root cause - WWDT stretch order, WCOMP wake direction, cold-boot-only AUTO_POWER_ON, rst_cause mirror
    [app_config.h, empty_mspm0c1104.c]
2026-08-13 fix(fw)+fix(debugger): 双键关机确认机制(灭灯≠standby, 确认松开且未满5s才进STANDBY0) + RMRDebugger烧录流程修复(halt+flash probe, 烧后清开机门控模拟冷启动自动亮灯); 三变体hex更新, exe更新
    [debugworkers.cpp, empty_mspm0c1104.c, hal_keys.c]
2026-08-14 docs+fw: 新增完整说明书(docs/RMR_说明书.md) + 无操作超时改为40分钟调暗/10分钟延迟关机(TIME_AUTO_DIM_S 3600->2400) + 六变体hex全部重建(DIRECT/BATT/ECO_D/ECO_B/DBG/DBGL) + README修复损坏条目
    [app_config.h]
2026-08-14 fix(fw): 修复ALS模式无法切回MAN - RUN熄灯后继续按满5s改为模式互切(区分OFF直接长按的ALS快捷开机), ALS故障锁定后允许切回手动; 六变体hex重建
    [empty_mspm0c1104.c, sys_mode.c]
2026-08-14 fix: 快速掉电瞬间断PWM+立即保存时序优化; 修复cfg_params镜像冻结; 说明书重构为用户手册+技术说明
    [app_config.h, empty_mspm0c1104.c]
2026-08-15 fix(fw): V4.3.4 修复上电自动开机失效 + STANDBY1 按键无法开机(唤醒加固)
    - 冷启动不再被 NVM off-intent 哨兵拦截: cold_boot || (!g_off_intent && !nvm_off_intent_get())
    - STANDBY1 唤醒加固: TIMG14 32k LFCLK 周期唤醒(~750ms)轮询按键, WUEN 保留即时唤醒,
    周期唤醒无按键跳过 battery_resume, 唤醒后显式恢复 4MHz/1ms tick
    - mailbox 尾部追加 sys_clk_khz + boot_refuse_reason (0xB8/0xBC, 结构 0xB8->0xC0)
    - RMRDebugger: 新增 Sys Clk / Boot Refuse 遥测显示, 重新编译, 更新内置 fw hex
    - 六变体 hex 重建 V4.3.4; 发布镜像 firmware/RMR.hex (V4.3.4_DIRECT); README 更新记录
    [app_config.h, debugworkers.cpp, empty_mspm0c1104.c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]
2026-08-15 fix(debugger): IPC port 7345 -> 17345 (Windows reserved range) + rebuild
    [mainwindow.cpp]
2026-08-15 fix(fw): V4.3.4 补丁 - SYSOSC 恒定24MHz修复计时快6倍(1.5s/5s不准) + g_off_pending自愈/双键状态复位修复关机不进STANDBY1
    [empty_mspm0c1104.c, hal_keys.c]
2026-08-15 fix(fw): 自动降亮度/关机计时改为tick差值(修复DIRECT/BATT忙等构建0.37/s漏计数) + mailbox新增standby_entry_cnt(0xC0) + RMRDebugger显示stby_cnt/修复sys_clk显示
    [debugworkers.cpp, empty_mspm0c1104.c, mainwindow.cpp]
2026-08-15 feat(fw): V4.3.5 量产版默认禁SWD/NRST(仅FLASH_MODE开放,复位后5s boot窗口) + STANDBY1移除750ms周期轮询(消除20uA尖峰) + 自动关机修正为40min调暗/50min关机 + ECO版FLASH_MODE最小遥测
    [app_config.h, empty_mspm0c1104.c]
2026-08-15 fix(debugger): 修复新构建启动崩溃 - monTexts 缺 stby_cnt 导致 monKeys 越界(QLabel越界); 发布修复版 rmrdebuger.exe + 内置固件更新为V4.3.5
    [mainwindow.cpp]
2026-08-15 fix(debugger): 连接/目标状态每5s周期刷新(不依赖轮询开关) + 丢失检测(Probe/Target Lost) + 自动烧录改为持续触发(勾选/选固件晚于连接也能烧) + 弹窗单例去重(同消息5s内不重复, 已有弹窗时更新置顶)
    [debugworkers.cpp, mainwindow.cpp]
2026-08-15 feat(debugger): 新增功能测试插件(LED PWM回显/光感暗亮/按键BT1+BT2/DM码, 引导式自动判定, 全过显示绿色PASS) + 实现DataMatrix ECC200编码器(ZXing移植, 与bwip-js逐模块验证一致) + DXF按钮改为显示DM码 + 弹窗改FIFO队列(同内容全链路仅一个,多余忽略)
2026-08-15 fix(debugger): 功能测试未选活动探针时给出提示不空跑
2026-08-15 feat(debugger): 功能测试光感步骤前自动切换到ALS模式(虚拟双键5s,结束恢复原模式) + 顶部显示DM码改为按钮旁内嵌小码(点击切换,去掉弹窗) + DM步骤去掉扫码引导 + LED步骤显示VBAT跌落辅助信息
2026-08-15 feat(debugger): 功能测试LED开路/短路判定(全亮VBAT压降+PowerZ电流交叉验证) + 测试倒计时显示 + 中途掉线暂停等待重连 + lux显示×0.01(OPT3001分辨率) + 参数栏常轮询(Fast Polling仅切间隔)
2026-08-15 feat(debugger): DM码改为最终产物(小码绘制在按钮上+点击放大弹窗, 移除测试步骤) + 去所有emoji扁平化UI + 去除标题括号/自动判定 + 测试记录数据库(芯片UUID/烧录器SN/过测状态时间/校准参数/固件版本/烧录时间, 重复测试upsert更新) + 功能测试页新增当前芯片历史记录子窗口
2026-08-15 feat(fw): V4.3.6 新增恢复出厂(仅用户侧配置, 保留校准值等参数) mailbox cmd 8 + 6变体重新构建
2026-08-15 fix(debugger): 功能测试 BT1/BT2 正负标注修正(BT1=-, BT2=+) + 测试结束自动恢复出厂(仅用户侧配置, 保留校准)
2026-08-15 docs: 新增 RMR 1:2.05 用户说明书 V1.0.0 (PDF + HTML 源)
2026-08-16 feat(fwsec): FWSEC1加密容器+构建工具+加密烧录, 额外信息仅存加密容器, 固件重建V4.3.6六变体默认DBGL
2026-08-16 tools: U盘一键同步脚本(hex六变体+双工具+自测+文档)
2026-08-16 feat(buildtool): 完整IPC(127.0.0.1:17346 JSON行协议, setdir/build/stop/encrypt/genpwd等命令+log/progress/build_finished/encrypt_finished广播) + 命令行预选工程目录 + 修复BuildRunner只clean不all导致hex为空 + 启动即选中目录
    [main.cpp, mainwindow.cpp]
2026-08-16 fix(fwsec): FIDO2硬件密钥UV改为DISCOURAGED, 触碰即可不再弹设置PIN弹窗(通行证/Windows Hello保持REQUIRED)
    [mainwindow.cpp]
2026-08-17 fix(fwsec): FIDO2安全密钥改直连CTAP2/HID+hmac-secret免PIN触碰即可
    Windows webauthn.dll 仅对驻留凭据暴露 PRF/hmac-secret, 非驻留凭据
    一律返回 NotSupportedError, 而驻留凭据强制 PIN/UV 与'触碰即可'冲突。
    新增 fwsec_ctap2: 直接枚举 FIDO HID 设备走 CTAPHID 协议, 创建非驻留
    凭据 + hmac-secret 扩展, getAssertion 免 PIN 触碰派生 32B 密钥。
    - webauthn_make_credential/get_prf_secret device=1 路由到 CTAP2
    - device=2 (Windows Hello/通行证) 保留 webauthn.dll PRF
    - 构建工具: FIDO 密钥派生移入加密线程(UI不冻结) + 触碰状态提示
    - 手机跨设备通行证不支持 PRF 时给出明确指引(改用 FIDO2 密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
    [mainwindow.cpp]
